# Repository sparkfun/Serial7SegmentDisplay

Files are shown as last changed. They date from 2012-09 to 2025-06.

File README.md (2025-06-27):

7-Segment Serial Display
========================

[7-Segment Serial Display  
*7-Segment Serial Display (COM-11629)*](https://www.sparkfun.com/products/11629)

The 7-Segment Serial Display combines a classic 4-digit 7-segment display and an ATMega328 microcontroller allowing you to control every segment individually using only a few serial lines.

Repository Contents
-------------------

* **/firmware** - Arduino firmware and test code
* **/hardware** - PCB design files (created with Eagle 6.1.0)

Documentation
--------------
* **[Hookup Guide](https://learn.sparkfun.com/tutorials/using-the-serial-7-segment-display)** - Basic hookup guide for the Serial Enabled 7-Segment Displays.
* **[Datasheet](https://github.com/sparkfun/Serial7SegmentDisplay/wiki/Serial-7-Segment-Display-Datasheet)** - Specifications

Product Versions
----------------

**[COM-11629](https://www.sparkfun.com/products/11629) - white, OEM packaging**  
The 7-Segment Serial Display with **white** segments in standard OEM packaging.

**[COM-11442](https://www.sparkfun.com/products/11442) - blue, OEM packaging**  
The 7-Segment Serial Display with **blue** segments in standard OEM packaging.

**[COM-11441](https://www.sparkfun.com/products/11441) - red, OEM packaging**  
The 7-Segment Serial Display with **red** segments in standard OEM packaging.

**[COM-11443](https://www.sparkfun.com/products/11443) - yellow, OEM packaging**  
The 7-Segment Serial Display with **yellow** segments in standard OEM packaging.

**[COM-11440](https://www.sparkfun.com/products/11440) - kelly green, OEM packaging**  
The 7-Segment Serial Display with **kelly green** segments in standard OEM packaging.

**[RTL-11381](https://www.sparkfun.com/products/11381) - blue, retail packaging**  
The 7-Segment Serial Display with **blue** segments in a retail-ready plastic clam shell.

**[RTL-11386](https://www.sparkfun.com/products/11386) - red, retail packaging**  
The 7-Segment Serial Display with **red** segments in a retail-ready plastic clam shell.

License Information
-------------------

All contents of this repository are released under [Creative Commons Share-alike 3.0](http://creativecommons.org/licenses/by-sa/3.0/).

Author
------

Jim Lindblom, [SparkFun Electronics](https://www.sparkfun.com)

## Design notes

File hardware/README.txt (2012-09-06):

////////////////////////////////
/// Serial 7-Segment Display ///
////////////////////////////////
/// PCB Design Files ///////////
////////////////////////////////

These files were created with Eagle 6.1.0.
Serial-7-Segment-Display.sch: Schematic
Serial-7-Segment-Display.brd: PCB Design

This project is Open-source Hardware!

License: Creative Commons Attribution-ShareAlike 3.0 (CC BY-SA 3.0)
http://creativecommons.org/licenses/by-sa/3.0/

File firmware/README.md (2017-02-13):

//////////////////////////////////////<br />
/// Serial 7-Segment Display /////////<br />
//////////////////////////////////////

This folder should live in your Arduino Sketchbook.

Serial 7-Segment Display: This folder contains the Serial 7-Segment Displays firmware and test/example Arduino code.

Support for this board in the Arduino IDE can be found in [this repository](https://github.com/sparkfun/Arduino_Boards/). That adds a "Serial 7-Segment Display" option to the boards menu within Arduino. If you reprogram the Display, you'll need this board selected. Special pin defines were required to make use of new pins 22 and 23 (PB6:7) (in variants/standard/pins_arduino.h). These pins are available on the Serial 7-Segment Display because it runs on the ATmega328's internal 8MHz oscillator.

This project is Open-source!

License: Creative Commons Attribution-ShareAlike 4.0 (CC BY-SA 4.0)
https://creativecommons.org/licenses/by-sa/4.0/

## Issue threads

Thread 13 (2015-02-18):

Adding custom boards does not work for Arduino 1.6.0

pinski1, 2015-02-18:
See https://github.com/arduino/Arduino/wiki/Arduino-Hardware-Cores-migration-guide-from-1.0-to-1.6

teachop, 2015-03-15:
Sparkfun is supporting building for the Serial 7 Segment in Arduino 1.6 here:
https://github.com/sparkfun/Arduino_Boards

Closed 2015-04-02.

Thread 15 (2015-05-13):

Missing 'E' Segment (COM-11440)

morganrallen, 2015-05-13:
This is an issue complained about in several comments across all of the 7 Segment product pages. Where everything appears normal, expect Segment 'E' on each digit does not display. I've verified the hardware is physically connected by switching pin assignments around and it does in fact light up.

Reading comments I've seen and tried several fixes.

Changing BOARD_TYPE to S7S.

Initially the text is totally scrambled, this change fixes it, except the E Segment.

Appending PB6/PB7 to pin_arduino.h

As I'm using the current code from this repo and (I think...) properly installing the hardware profile, this is taken care of for me.

I'm using Arduino 1.6.4

BrentWilkins, 2015-05-14:
I'm a little confused if this is a question/issue.  Are you appending PB6/PB7 to pin_arduino.h?  The copy of pins_arduino.h that is in this repo has had that for 3 years.  Did you change something?  Does 'Changing BOARD_TYPE to S7S' mean you changed line #39 of Serial_7_Segment_Display_Firmware.ino (#define DISPLAY_TYPE OPENSEGMENT) to use the S7S settings?

morganrallen, 2015-05-14:
Sorry for the lack of clarity.
I've not added anything to pins_arduino.h, as you've said it's present, but that is part of what I found to be a suggested solution.

And yes, I've changed #define BOARD_TYPE to S7S. Which leads to better results than default but still seems to miss segment E.

jimblom, 2015-05-14:
I think I've tracked the problem down. The build variant was set incorrectly to "standard", so _pins\_arduino.h_ wasn't being pulled from our custom hardware folder.

I pushed a new version of boards.txt, if you want to try that out. Or just make sure [this line](https://github.com/sparkfun/Serial7SegmentDisplay/blob/master/firmware/hardware/Serial7Seg/boards.txt#L17) says "ser7seg" not "standard".

morganrallen, 2015-05-14:
But wouldn't that require the directory `variant/ser7seg` to exist with it's own pin_arduino.h?

```
In file included from /home/morgan/opt/arduino-1.6.4/libraries/SevSeg/src/SevSeg.h:14:0,
                 from Serial_7_Segment_Display_Firmware.ino:1:
/home/morgan/opt/arduino-1.6.4/hardware/Serial7Seg/avr/cores/arduino/Arduino.h:213:26: fatal error: pins_arduino.h: No such file or directory
 #include "pins_arduino.h"
```

BrentWilkins, 2015-05-14:
It does. https://github.com/sparkfun/Serial7SegmentDisplay/blob/master/firmware/hardware/Serial7Seg/variants/standard/pins_arduino.h
Maybe do a fresh download?

morganrallen, 2015-05-14:
Same error with a fresh checkout. If I set `variant` to `ser7seg` it cannot find `pins_arduino.h`.

jimblom, 2015-05-14:
@morganrallen is right. "standard" should be renamed "ser7seg". Those changes are pushed now.

Bigger picture issue here is the hardware folder structure in general needs to be revised to match Arduino 1.6 standards. I'll keep this issue open until we resolve that.

morganrallen, 2015-05-14:
Right, I've had to add the `avr` directory to even get it to load, platforms.txt is missing also.

morganrallen, 2015-05-14:
So simply renaming everything hasn't worked. I got it back to a compiling state but Segment E remains dark.

jimblom, 2015-05-14:
Another change pushed. Moved all hardware addon files to `hardware/sparkfun/avr`, and added platform.txt. Seems to be working for me - compiles and the E segment lights up. Let me know if it tests out for you @morganrallen .

morganrallen, 2015-05-14:
No dice.

BrentWilkins, 2017-02-13:
I cannot reproduce the error. What do you mean by the 'E' segment? Is it a single segment that is numbered in a figure in [this section](https://github.com/sparkfun/Serial7SegmentDisplay/wiki/Special-Commands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)? If so, which digit(s)?

morganrallen, 2017-02-16:
Yes, E is the same as 5.

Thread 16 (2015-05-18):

Display something on power up

josephernest, 2015-05-18:
I'm using the 7segment display with a raspberry pi.
During the Linux booting time (~15 seconds), the 7segment display **displays nothing**.

Is it possible to show  "___", "----"  once it is powered up?

So the user will know the system is "booting".

How to do this?

jimblom, 2015-05-18:
Sure, this is a relatively simple modification. The four variable assignments starting [here](https://github.com/sparkfun/Serial7SegmentDisplay/blob/master/firmware/Serial%207-Segment%20Display/Serial_7_Segment_Display_Firmware/Serial_7_Segment_Display_Firmwa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) set what the display shows on start-up.

For example, to make the display show "----", swap in these four lines of code:

    display.digits[0] = '-';
    display.digits[1] = '-';
    display.digits[2] = '-';
    display.digits[3] = '-';

josephernest, 2015-05-18:
So do you mean it should *already* display something on power up?  (it seems, in your code, that `1234` should be displayed on power up, or am I wrong?).

I just tried by connecting +5V and GND only  (and no serial, no I2C), but nothing is displayed.

When exactly should these default letters happen? Really when +5V comes ? or is there another trigger for the "startup"?

Closed 2015-05-18.

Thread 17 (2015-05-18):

Refresh rate / flicker

josephernest, 2015-05-18:
I'm currently filming my hardware project (including a 7seg display) with a camera.

The result is *flickering* because probably the refresh rate does not fit well with 24fps or 30fps of my camera.

Any idea on how to change refresh rate of Serial7SegmentDisplay?

jimblom, 2015-05-18:
You'll have to modify the [SevSeg library](https://github.com/sparkfun/SevSeg) to achieve this. The constant `FRAMEPERIOD`, defined [here](https://github.com/sparkfun/SevSeg/blob/master/src/SevSeg.h#L28) is probably the best place to begin experimenting. Try turning it to somewhere between 500-1000.

josephernest, 2015-05-18:
In fact the problem has been solved by changing the shutter speed of the
camera (didn't know it was possible in "Movie" mode).
Setting shutter speed to 1/30 or 1/50 worked.

On Mon, May 18, 2015 at 5:09 PM, Jim Lindblom <notifications@github.com>
wrote:

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

Closed 2015-05-18.

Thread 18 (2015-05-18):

Error check

josephernest, 2015-05-18:
I use Serial7SegmentDisplay with a RaspberryPi. It works both with I2C, and with Serial.

Everything is fine 90% of the time. But sometimes, some characters are not well sent/received by the display, and one character is missing. This is happening for some other people (I found on some forums).

Could we add basic error check, so that if a byte is not well received, the serial or SPI interface will resend?

Tried:

* sleep 5 ms between each byte send, it improves a bit but does not solve 100%
* change bps rate, but doesn't change anything

glebtv, 2015-06-06:
https://github.com/sparkfun/Serial7SegmentDisplay/blob/master/firmware/Serial%207-Segment%20Display/Serial_7_Segment_Display_Firmware/Serial_7_Segment_Display_Firmwa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

I think it's a bug somewhere here, whenever you set a 0x76 to the display it clears and moves cursor
Example (setting brightness to 117)
```
s7sSendStringI2C("TEST");
delay(500);
Wire.beginTransmission(s7sAddress);
Wire.write(0x7A);  // Set brightness command byte
Wire.write(0x76);  // brightness data byte
Wire.endTransmission();
delay(500);
```

josephernest, 2015-06-07:
@glebtv What do you mean?

Do you think it's impossible to send a 0x76 value for brightness for example? It will always clear the display?

I cannot test now, but are you sure?
@jimblom what do you think?

glebtv, 2015-07-19:
Yes, the firmware code checks for reset before checking for anything else so sending 0x76 (reset) as brightness or any other DATA it resets the display - which gives exactly the effect described in this issue - a couple characters will be missing from display.
I found that accidentally by testing different brightness levels in a loop.

See code I linked https://github.com/sparkfun/Serial7SegmentDisplay/blob/master/firmware/Serial%207-Segment%20Display/Serial_7_Segment_Display_Firmware/Serial_7_Segment_Display_Firmwa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

jimblom, 2016-01-21:
Sorry to be so late on this. I've added a check for a current commandMode before clearing the display. That seems to fix the bug.

Closed 2016-01-21.

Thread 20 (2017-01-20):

Display refresh rate

MNewman, 2017-01-20:
I've noticed that when viewed on a 60fps camera the display visibly flickers. I assume this has something to do with the rate at which the segments are illuminated. I'm also assuming that one potential remedy would be adjusting the shutter rate of the camera.

Is dimming accomplished by leaving each segment on a smaller slice of time? Is there a way to increase the speed of redrawing the segments to overcome the aliasing effect on the camera?

bboyho, 2020-06-02:
Hi,

Sorry, I just noticed this question when browsing our issues. If you are still wondering, the brightness uses an internal PWM with a work around. The work around turns on and off the segments at a certain speed. This speed is probably not synced with your camera which is what you are seeing with the flicker. If you were adjusting the code, you may need to adjust the [`SetBrightness()` function in the library](https://github.com/sparkfun/SevSeg/blob/master/src/SevSeg.cpp#L175) and reupload the [default firmware](https://github.com/sparkfun/Serial7SegmentDisplay/tree/master/firmware/Serial%207-Segment%20Display/Serial_7_Segment_Display_Firmware). Looking online, it looks like users implemented the `millis()` function in their sketch and only updated the segments after a certain amount of time had passed.

I don't know too much about DSLR cameras. Doing some research online, it seems like the flicker can be avoided by adjusting the shutter speed to match the time of the segments turning on and off. Another technique would be to adjust the frame rate equal to the period of the segments blinking as well. These two techniques seem to be used to compensate for flickers in general.

You may want to post in the following forums to see if anyone else in the community has additional insight. It appears that this question about the flickering has been asked a few times in the Arduino forums. Otherwise, you would need to experiment with the code or your camera's settings if you are still having this problem.

* {SparkFun Forums](https://forum.sparkfun.com/)
* [Arduino Forums](https://forum.arduino.cc/)

Closed 2020-06-02.

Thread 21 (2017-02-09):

basic display driver

Dc2LightTech, 2017-02-09:
I need to display temperatures from -99.9 to 99.9 (with the leading digit blanked when the value is positive.
I will be driving 10 serial displays and I need to assign the CS pin.

BrentWilkins, 2017-02-09:
Thanks for reaching out. The specific issue you are commenting on here is unclear. If you have found a specific bug in our code, please let us know. Otherwise, if you are simply looking to modify the code for your personal project, we have an example sketch for changing the SPI settings [here](https://github.com/sparkfun/Serial7SegmentDisplay/blob/master/firmware/Serial%207-Segment%20Display/Arduino_Examples/S7S_Example_SPI_Settings/S7S_Example_SPI_Setting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).

Dc2LightTech, 2017-02-09:
thanks for the reply. when I used ProMini's the example code worked well.
this was like 5 years ago. Now I only use Teency's and the example code
mostly does not work. the new GitHub SPI Bus code for the displays from:
https://github.com/sparkfun/Serial7SegmentDisplay don't have chip and stuff
for example, the folloning code is not helpull in getting basic display
operation    S7S_EcampleSerial_Basic:  ( I would like to display{-12.3}

/*
 9-23-2012
 Spark Fun Electronics
 Nathan Seidle

 This code is public domain but you buy me a beer if you use this and we
meet someday (Beerware license).
 Serial7Segment is an open source seven segment display.
 This is example code that shows how to display basic numbers on the
display.

 Note: This code expects the display to be listening at 9600bps. If your
display is not at 9600bps, you can
 do a software or hardware reset. See the Wiki for more info:

http://github.com/sparkfun/Serial7SegmentDisplay/wiki/Special-Commands#wiki-baud

 To get this code to work, attached an Serial7Segment to an Arduino Uno
using the following pins:
 Pin 8 on Uno (software serial TX) to RX on Serial7Segment
 VIN to PWR
 GND to GND

*/
#include <SoftwareSerial.h>
SoftwareSerial Serial7Segment(7, 8); //RX pin, TX pin
int cycles = 0;
void setup() {
  Serial.begin(9600);
  Serial.println("OpenSegment Example Code");
  Serial7Segment.begin(9600); //Talk to the Serial7Segment at 9600 bps
  Serial7Segment.write('v'); //Reset the display - this forces the cursor
to return to the beginning of the display
}
void loop()
{
  cycles++; //Counting cycles! Yay!
  Serial.print("Cycle: ");
  Serial.println(cycles);

  char tempString[10]; //Used for sprintf
  sprintf(tempString, "%4d", cycles); //Convert deciSecond into a string
that is right adjusted
  //sprintf(tempString, "%d", cycles); //Convert deciSecond into a string
that is left adjusted (requires digit 1 command)
  //sprintf(tempString, "%04d", cycles); //Convert deciSecond into a string
with leading zeros
  //sprintf(tempString, "%4X", cycles); //Count in HEX, right adjusted
  //int negativeCycles = cycles * -1;
  //sprintf(tempString, "%4d", negativeCycles); //Shows a negative sign
infront of right adjusted number
  //Note: This method works well as long as your number is less than or
equal to 4 digits.
  //14422 will cause the display to wrap (5 digits)
  //-5766 will cause the display to wrap (5 digits)
  //To fix this, send a 'v' character or look at how to control the digit
placement
  //
https://github.com/sparkfun/Serial7SegmentDisplay/wiki/Basic-Usage#wiki-cursor
  Serial7Segment.print(tempString); //Send serial string out the soft
serial port to the S7S
  delay(10);
}

On Thu, Feb 9, 2017 at 2:13 PM, Brent Wilkins <notifications@github.com>
wrote:

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

BrentWilkins, 2017-02-14:
I wasn't able to reproduce any issues with the code found in S7S_Example_Serial_Basic on a Teensy. I wired up the TX line on the Teensy (8) to the RX line in the display module. To display your example of "-12.3" I replaced the contents of `loop()` with the following code:

```c++
// Writing 4 digits each time. In this case no need to clear display.
Serial7Segment.print("-123");
Serial7Segment.write(0x77); // Decimal control command
Serial7Segment.write(0b00000100); // Turns on tenths decimal
```

In other cases you might want to send the reset command (RESET_CMD | 0x76 | 'v') first. This might be `Serial7Segment.print("v-123");` for this case.

If you want to modify the firmware to handle numbers rather than ASCII characters and commands, take a look at the `void SevSeg::DisplayString(const char*, byte)` method found [here](https://github.com/sparkfun/SevSeg/blob/master/src/SevSeg.cpp). I replaced line 114 in [the firmware](https://github.com/sparkfun/Serial7SegmentDisplay/blob/master/firmware/Serial%207-Segment%20Display/Serial_7_Segment_Display_Firmware/Serial_7_Segment_Display_Firmwa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) `myDisplay.DisplayString(display.digits, display.decimals);` with `myDisplay.DisplayString("-123", 4);` to display `-12.3`.

Do you have our SevSeg library installed? If you have the original library that we forked, not ours, you will get errors such as `error: 'class SevSeg' has no member named 'DisplayString'`.

Dc2LightTech, 2017-02-15:
could you send the entire code please. This code is SPI not I2C, right?

On Tue, Feb 14, 2017 at 4:20 PM, Brent Wilkins <notifications@github.com>
wrote:

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

BrentWilkins, 2017-02-15:
Here is the entire sketch minus the copyright and such in the header.

```C++
#include <SoftwareSerial.h>

SoftwareSerial Serial7Segment(7, 8); //RX pin, TX pin

int cycles = 0;

void setup() {

  Serial.begin(9600);
  delay(4000);
  Serial.println("OpenSegment Example Code");

  Serial7Segment.begin(9600); //Talk to the Serial7Segment at 9600 bps
  Serial7Segment.write('v'); //Reset the display - this forces the cursor to return to the beginning of the display
}

void loop()
{
  Serial.println("Displaying: -12.3");
  // Writing 4 digits each time. In this case no need to clear display.
  Serial7Segment.print("-123");
  Serial7Segment.write(0x77); // Decimal control command
  Serial7Segment.write(0b00000100); // Turns on tenths decimal
}
```
The first line includes the file with the [software UART implementation](https://www.arduino.cc/en/Reference/softwareSerial). The next line of code creates an instance of the SoftwareSerial class named `Serial7Segment` that uses pins 7 & 8.
If you want to use SPI instead, I recommend looking at our [SPI example](https://github.com/sparkfun/Serial7SegmentDisplay/blob/master/firmware/Serial%207-Segment%20Display/Arduino_Examples/S7S_Example_SPI_Basic/S7S_Example_SPI_Basic.ino).

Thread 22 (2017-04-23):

Analog inputs

OmriShi, 2017-04-23:
Hi,
My name is Omri, and I'm considering the use of your nice S7S for a project I'm working on.

The main goal is using this S7S to display voltage measurements. By considering the 2 analog input pins there is on the breakout board it could be more simple than I thought.

After reading the "Hardware specifications" I'm a little bit confused.
With the current stat of the breakout and firmware,  can I use the pins to measure the analog voltage?
and if I can, what is the voltage limitation?

I hope I was clear, thanks for helping

bboyho, 2019-05-16:
Hi,

I'm sorry for the delay in reply. I was browsing the issues in our GitHub repo when I noticed your question. This is a more technical question and it does not seem to be an issue with the board. It might have been better to have checked in the SparkFun Forums. However, here are some of my thoughts regarding your question if you are still working on the project:

The voltage limitation on the pins depends on the input voltage (Vcc). As stated in the Hardware Overview in the [Wiki](https://github.com/sparkfun/Serial7SegmentDisplay/wiki/Hardware-specifications) and [associated tutorial](https://learn.sparkfun.com/tutorials/using-the-serial-7-segment-display#hardware-overview), it is **3.0V to 5.5V**. Based on the input voltage of the ATmega328P as stated in the [datasheet under the **Absolute Maximum Rating**](http://ww1.microchip.com/downloads/en/DeviceDoc/Atmel-7810-Automotive-Microcontrollers-ATmega328P_Datasheet.pdf), that should be about Vcc+/-0.5V on any I/O pin. So if you are powering the device with 3.3V, the limitation on the pins is about 3.3V.

However, using a [voltage divider](https://learn.sparkfun.com/tutorials/voltage-dividers/all#applications), you can theoretically measure higher voltage than your input voltage. I have not tried the method using resistors before but here's one example that I found online => [ [https://startingelectronics.org/articles/arduino/measuring-voltage-with-arduino](https://startingelectronics.org/articles/arduino/measuring-voltage-with-arduino/) ]. You would just need to adjust the default firmware that is loaded on the board to measure and display the values on the 7 segments display.

Otherwise, try looking at this dedicated [digital 7-segment LED Voltmeter](https://www.sparkfun.com/products/14313).

Closed 2019-05-16.

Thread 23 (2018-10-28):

Technical data for Sparkfun PCB missing -- measures provided

sorenoneill, 2018-10-28:
I have searched but not been able to find the technical data for the PCB dimensions. Data is available for the 7-segment display itself, but not the PCB.

These are my measures using a caliper:

width: 41.3mm
depth: 23.5mm
thickness: 1.6mm

stand-off holes diameter: 3.0mm
stand-off holes width offset (to center of hole): 5.2 (possibly should be 0.2in)
stand-off holes depth offset (to center of hole): 2.7 (possibly should be 0.1in)

bboyho, 2019-02-12:
Hi,

Thanks for the measurements. The dimensions (except for the PCB thickness) are actually provided in inches under the [hardware specifications under this repository's Wiki](https://github.com/sparkfun/Serial7SegmentDisplay/wiki/Hardware-specifications#physical-dimensions):

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

I'll be closing this issue out. =)

Closed 2019-02-12.

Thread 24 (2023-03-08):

Compilation Error

Tommy38cal, 2023-03-08:
Hi,
I am getting two compilation errors in the Arduino IDE. One was a capitalization error on setBrightness. The other is

Compilation error: 'class SevSeg' has no member named 'displayString'

I couldn't find this function in the SevSeg .cpp or .h. Can you advise? I thought it might have just been a mistake and looked for other ones that have the same inputs but to no avail. I think setChars was the closest.

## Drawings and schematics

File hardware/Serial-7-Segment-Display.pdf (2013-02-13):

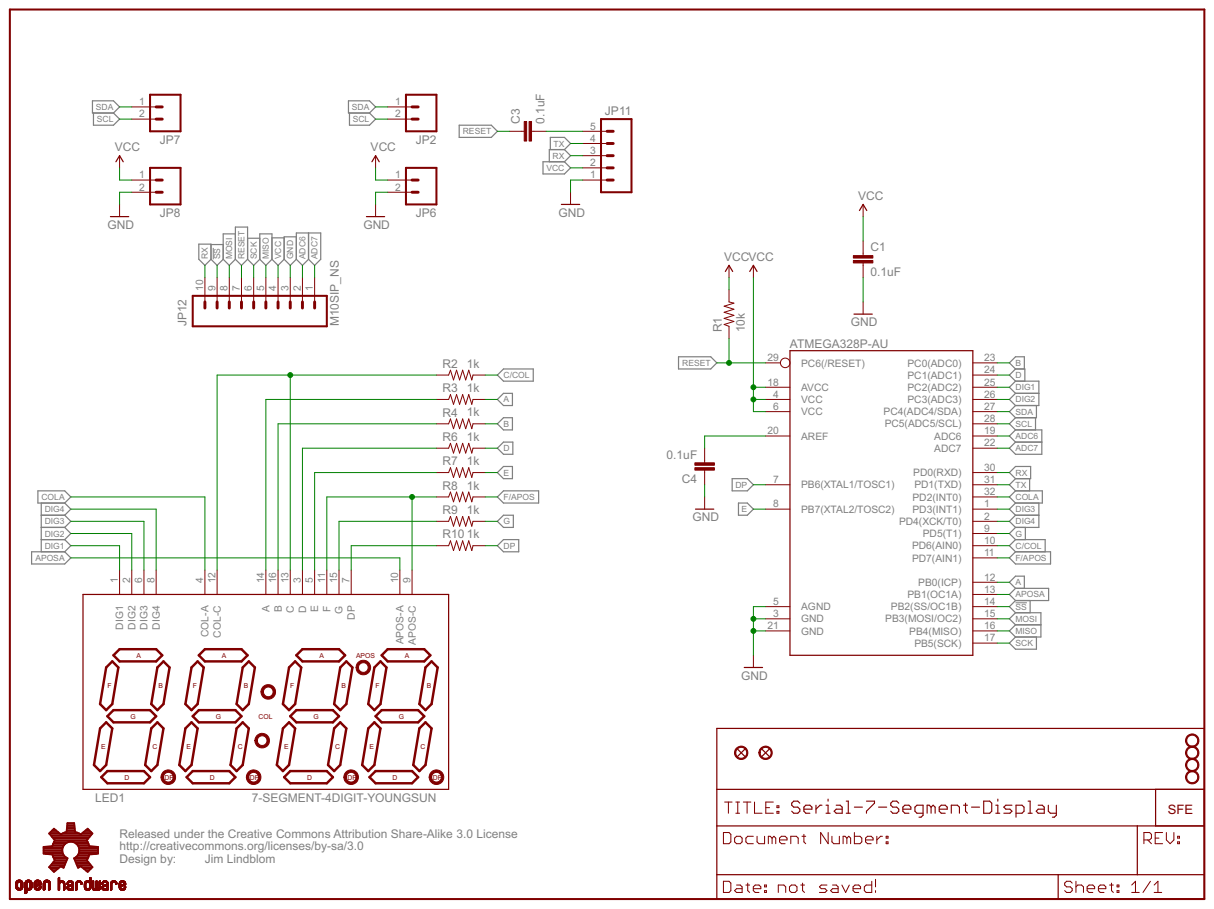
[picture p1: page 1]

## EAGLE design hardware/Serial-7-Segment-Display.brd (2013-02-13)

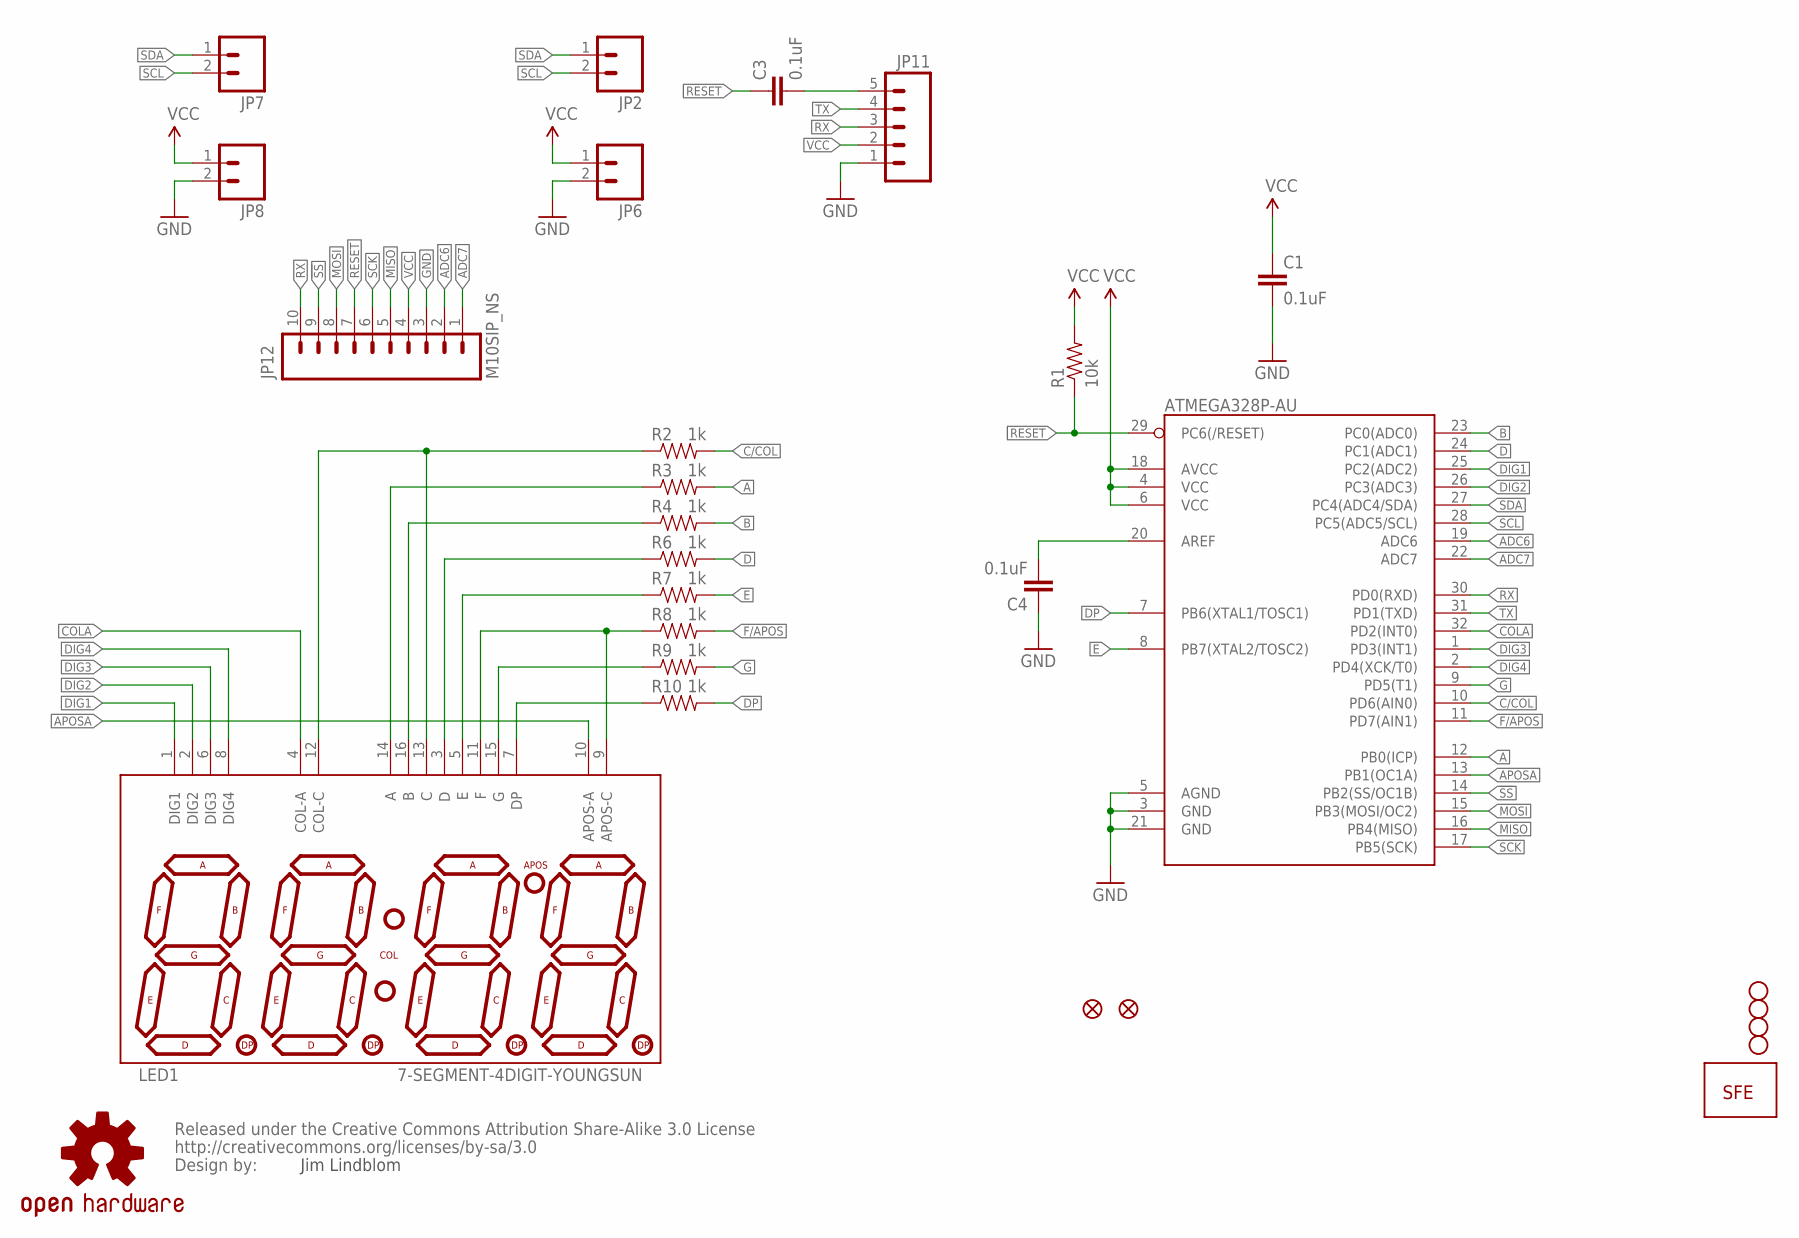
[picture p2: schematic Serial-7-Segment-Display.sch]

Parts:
ATMEGA328P-AU: ATMEGA328P-AU; TQFP32-08
C1, C3, C4: 0.1uF; 0402-CAP
JP1, JP3, JP4, JP5: STAND-OFF
JP2, JP6, JP7, JP8: M021X02_NO_SILK; 1X02_NO_SILK
JP9, JP10: FIDUCIALUFIDUCIAL; MICRO-FIDUCIAL
JP11: M05PTH-NS; 1X05_NO_SILK
JP12: M10SIP_NS; 1X10_NO_SILK
LED1: 7-SEGMENT-4DIGIT-YOUNGSUN
R1: 10k; 0402-RES
R2, R3, R4, R6, R7, R8, R9, R10: 1k; 0402-RES
U$1: CREATIVE_COMMONS
U$2: LOGO-SFESK; SFE-LOGO-FLAME
U$4: OSHW-LOGOS; OSHW-LOGO-S

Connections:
!SS: ATMEGA328P-AU.14 (PB2(SS/OC1B)), JP12.9
A: ATMEGA328P-AU.12 (PB0(ICP)), R3.2
ADC6: ATMEGA328P-AU.19 (ADC6), JP12.2
ADC7: ATMEGA328P-AU.22 (ADC7), JP12.1
APOSA: ATMEGA328P-AU.13 (PB1(OC1A)), LED1.10 (APOS-A)
B: ATMEGA328P-AU.23 (PC0(ADC0)), R4.2
C/COL: ATMEGA328P-AU.10 (PD6(AIN0)), R2.2
COLA: ATMEGA328P-AU.32 (PD2(INT0)), LED1.4 (COL-A)
D: ATMEGA328P-AU.24 (PC1(ADC1)), R6.2
DIG1: ATMEGA328P-AU.25 (PC2(ADC2)), LED1.1 (DIG1)
DIG2: ATMEGA328P-AU.26 (PC3(ADC3)), LED1.2 (DIG2)
DIG3: ATMEGA328P-AU.1 (PD3(INT1)), LED1.6 (DIG3)
DIG4: ATMEGA328P-AU.2 (PD4(XCK/T0)), LED1.8 (DIG4)
DP: ATMEGA328P-AU.7 (PB6(XTAL1/TOSC1)), R10.2
E: ATMEGA328P-AU.8 (PB7(XTAL2/TOSC2)), R7.2
F/APOS: ATMEGA328P-AU.11 (PD7(AIN1)), R8.2
G: ATMEGA328P-AU.9 (PD5(T1)), R9.2
GND: ATMEGA328P-AU.3 (GND), ATMEGA328P-AU.5 (AGND), ATMEGA328P-AU.21 (GND), C1.2, C4.1, JP6.2, JP8.2, JP11.1, JP12.3
MISO: ATMEGA328P-AU.16 (PB4(MISO)), JP12.5
MOSI: ATMEGA328P-AU.15 (PB3(MOSI/OC2)), JP12.8
unnamed: ATMEGA328P-AU.20 (AREF), C4.2
unnamed: LED1.7 (DP), R10.1
unnamed: LED1.15 (G), R9.1
unnamed: LED1.9 (APOS-C), LED1.11 (F), R8.1
unnamed: LED1.5 (E), R7.1
unnamed: LED1.3 (D), R6.1
unnamed: LED1.16 (B), R4.1
unnamed: LED1.14 (A), R3.1
unnamed: LED1.12 (COL-C), LED1.13 (C), R2.1
unnamed: C3.2, JP11.5
RESET: ATMEGA328P-AU.29 (PC6(/RESET)), C3.1, JP12.7, R1.1
RX: ATMEGA328P-AU.30 (PD0(RXD)), JP11.3, JP12.10
SCK: ATMEGA328P-AU.17 (PB5(SCK)), JP12.6
SCL: ATMEGA328P-AU.28 (PC5(ADC5/SCL)), JP2.2, JP7.2
SDA: ATMEGA328P-AU.27 (PC4(ADC4/SDA)), JP2.1, JP7.1
TX: ATMEGA328P-AU.31 (PD1(TXD)), JP11.4
VCC: ATMEGA328P-AU.4 (VCC), ATMEGA328P-AU.6 (VCC), ATMEGA328P-AU.18 (AVCC), C1.1, JP6.1, JP8.1, JP11.2, JP12.4, R1.2

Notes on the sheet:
Jim Lindblom

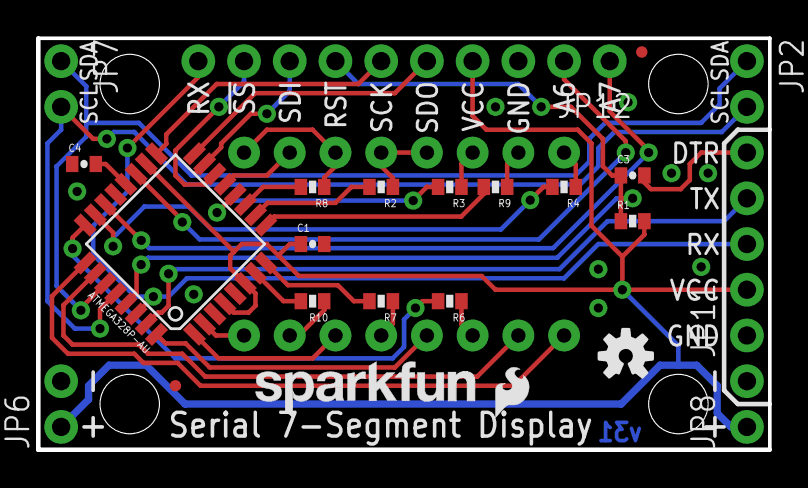
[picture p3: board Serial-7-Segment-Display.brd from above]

Board: 2 copper layers, 40.6 x 22.9 mm, 30 parts (1 on the bottom side), 37 nets.

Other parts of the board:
U$3: LOGO-SFENW2; SFE-NEW-WEB

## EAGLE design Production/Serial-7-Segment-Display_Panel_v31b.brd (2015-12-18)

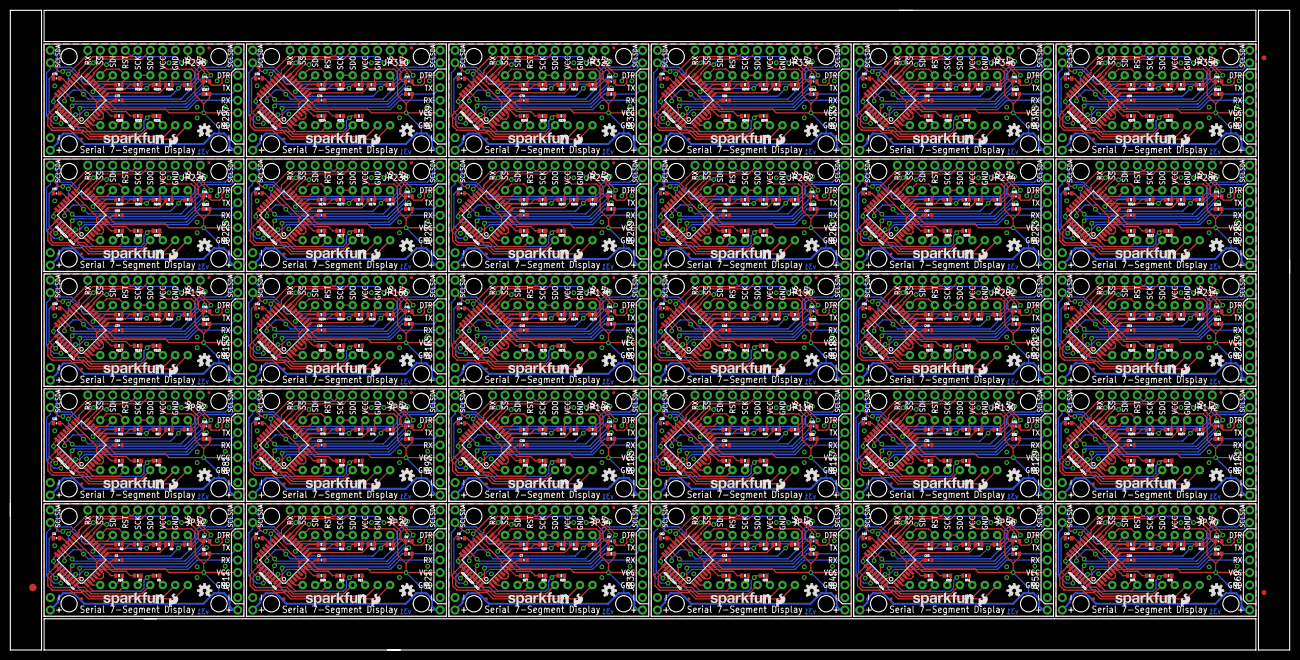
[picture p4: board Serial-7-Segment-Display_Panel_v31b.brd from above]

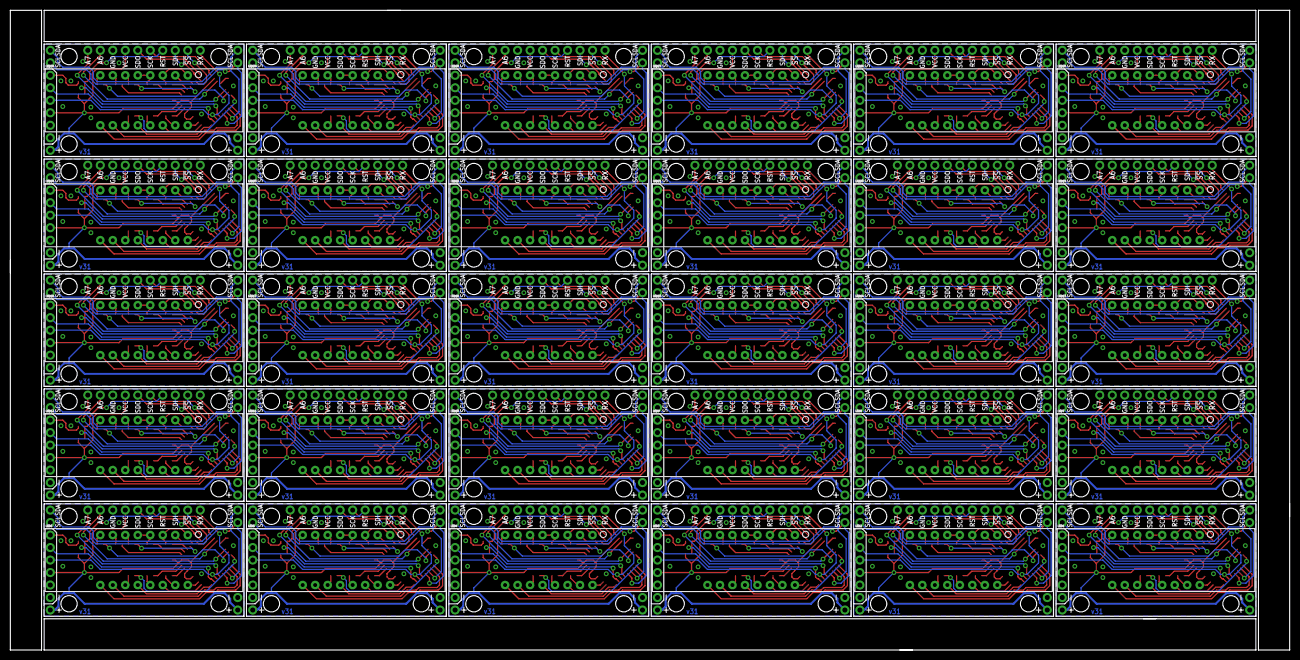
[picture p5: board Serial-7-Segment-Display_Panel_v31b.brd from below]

Board: 2 copper layers, 260.1 x 130.0 mm, 873 parts (30 on the bottom side), 1110 nets.

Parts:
ATMEGA328P-AU, ATMEGA328P-AU1, ATMEGA328P-AU2, ATMEGA328P-AU3, ATMEGA328P-AU4, ATMEGA328P-AU5, ATMEGA328P-AU6, ATMEGA328P-AU7, ATMEGA328P-AU8, ATMEGA328P-AU9, ATMEGA328P-AU10, ATMEGA328P-AU11, ATMEGA328P-AU12, ATMEGA328P-AU13, ATMEGA328P-AU14, ATMEGA328P-AU15, ATMEGA328P-AU16, ATMEGA328P-AU17, ATMEGA328P-AU18, ATMEGA328P-AU19, ATMEGA328P-AU20, ATMEGA328P-AU21, ATMEGA328P-AU22, ATMEGA328P-AU23, ATMEGA328P-AU24, ATMEGA328P-AU25, ATMEGA328P-AU26, ATMEGA328P-AU27, ATMEGA328P-AU28, ATMEGA328P-AU29: ATMEGA328P-AU; TQFP32-08
C1, C2, C3, C4, C5, C6, C7, C8, C9, C10, C11, C12, C13, C14, C15, C16, C17, C18, C19, C20, C21, C22, C23, C24, C25, C26, C27, C28, C29, C30, C31, C32, C33, C34, C35, C36, C37, C38, C39, C40, C41, C42, C43, C44, C45, C46, C47, C48, C49, C50, C51, C52, C53, C54, C55, C56, C57, C58, C59, C60, C61, C62, C63, C64, C65, C66, C67, C68, C69, C70, C71, C72, C73, C74, C75, C76, C77, C78, C79, C80, C81, C82, C83, C84, C85, C86, C87, C88, C89, C90: 0.1uF; 0402-CAP
E$1: FIDUCIAL-1.5X3
E$5, E$6: FIDUCIAL-1X2
JP1, JP3, JP4, JP5, JP13, JP14, JP15, JP16, JP25, JP26, JP27, JP28, JP37, JP38, JP39, JP40, JP49, JP50, JP51, JP52, JP61, JP62, JP63, JP64, JP73, JP74, JP75, JP76, JP85, JP86, JP87, JP88, JP97, JP98, JP99, JP100, JP109, JP110, JP111, JP112, JP121, JP122, JP123, JP124, JP133, JP134, JP135, JP136, JP145, JP146, JP147, JP148, JP157, JP158, JP159, JP160, JP169, JP170, JP171, JP172, JP181, JP182, JP183, JP184, JP193, JP194, JP195, JP196, JP205, JP206, JP207, JP208, JP217, JP218, JP219, JP220, JP229, JP230, JP231, JP232, JP241, JP242, JP243, JP244, JP253, JP254, JP255, JP256, JP265, JP266, JP267, JP268, JP277, JP278, JP279, JP280, JP289, JP290, JP291, JP292, JP301, JP302, JP303, JP304, JP313, JP314, JP315, JP316, JP325, JP326, JP327, JP328, JP337, JP338, JP339, JP340, JP349, JP350, JP351, JP352: STAND-OFF
JP2, JP6, JP7, JP8, JP17, JP18, JP19, JP20, JP29, JP30, JP31, JP32, JP41, JP42, JP43, JP44, JP53, JP54, JP55, JP56, JP65, JP66, JP67, JP68, JP77, JP78, JP79, JP80, JP89, JP90, JP91, JP92, JP101, JP102, JP103, JP104, JP113, JP114, JP115, JP116, JP125, JP126, JP127, JP128, JP137, JP138, JP139, JP140, JP149, JP150, JP151, JP152, JP161, JP162, JP163, JP164, JP173, JP174, JP175, JP176, JP185, JP186, JP187, JP188, JP197, JP198, JP199, JP200, JP209, JP210, JP211, JP212, JP221, JP222, JP223, JP224, JP233, JP234, JP235, JP236, JP245, JP246, JP247, JP248, JP257, JP258, JP259, JP260, JP269, JP270, JP271, JP272, JP281, JP282, JP283, JP284, JP293, JP294, JP295, JP296, JP305, JP306, JP307, JP308, JP317, JP318, JP319, JP320, JP329, JP330, JP331, JP332, JP341, JP342, JP343, JP344, JP353, JP354, JP355, JP356: 1X02_NO_SILK
JP9, JP10, JP23, JP24, JP35, JP36, JP47, JP48, JP59, JP60, JP71, JP72, JP83, JP84, JP95, JP96, JP107, JP108, JP119, JP120, JP131, JP132, JP143, JP144, JP155, JP156, JP167, JP168, JP179, JP180, JP191, JP192, JP203, JP204, JP215, JP216, JP227, JP228, JP239, JP240, JP251, JP252, JP263, JP264, JP275, JP276, JP287, JP288, JP299, JP300, JP311, JP312, JP323, JP324, JP335, JP336, JP347, JP348, JP359, JP360: FIDUCIALUFIDUCIAL; MICRO-FIDUCIAL
JP11, JP21, JP33, JP45, JP57, JP69, JP81, JP93, JP105, JP117, JP129, JP141, JP153, JP165, JP177, JP189, JP201, JP213, JP225, JP237, JP249, JP261, JP273, JP285, JP297, JP309, JP321, JP333, JP345, JP357: 1X05_NO_SILK
JP12, JP22, JP34, JP46, JP58, JP70, JP82, JP94, JP106, JP118, JP130, JP142, JP154, JP166, JP178, JP190, JP202, JP214, JP226, JP238, JP250, JP262, JP274, JP286, JP298, JP310, JP322, JP334, JP346, JP358: M10SIP_NS; 1X10_NO_SILK
LED1, LED2, LED3, LED4, LED5, LED6, LED7, LED8, LED9, LED10, LED11, LED12, LED13, LED14, LED15, LED16, LED17, LED18, LED19, LED20, LED21, LED22, LED23, LED24, LED25, LED26, LED27, LED28, LED29, LED30: 7-SEGMENT-4DIGIT-YOUNGSUN
R1, R5, R19, R28, R37, R46, R55, R64, R73, R82, R91, R100, R109, R118, R127, R136, R145, R154, R163, R172, R181, R190, R199, R208, R217, R226, R235, R244, R253, R262: 10k; 0402-RES
R2, R3, R4, R6, R7, R8, R9, R10, R11, R12, R13, R14, R15, R16, R17, R18, R20, R21, R22, R23, R24, R25, R26, R27, R29, R30, R31, R32, R33, R34, R35, R36, R38, R39, R40, R41, R42, R43, R44, R45, R47, R48, R49, R50, R51, R52, R53, R54, R56, R57, R58, R59, R60, R61, R62, R63, R65, R66, R67, R68, R69, R70, R71, R72, R74, R75, R76, R77, R78, R79, R80, R81, R83, R84, R85, R86, R87, R88, R89, R90, R92, R93, R94, R95, R96, R97, R98, R99, R101, R102, R103, R104, R105, R106, R107, R108, R110, R111, R112, R113, R114, R115, R116, R117, R119, R120, R121, R122, R123, R124, R125, R126, R128, R129, R130, R131, R132, R133, R134, R135, R137, R138, R139, R140, R141, R142, R143, R144, R146, R147, R148, R149, R150, R151, R152, R153, R155, R156, R157, R158, R159, R160, R161, R162, R164, R165, R166, R167, R168, R169, R170, R171, R173, R174, R175, R176, R177, R178, R179, R180, R182, R183, R184, R185, R186, R187, R188, R189, R191, R192, R193, R194, R195, R196, R197, R198, R200, R201, R202, R203, R204, R205, R206, R207, R209, R210, R211, R212, R213, R214, R215, R216, R218, R219, R220, R221, R222, R223, R224, R225, R227, R228, R229, R230, R231, R232, R233, R234, R236, R237, R238, R239, R240, R241, R242, R243, R245, R246, R247, R248, R249, R250, R251, R252, R254, R255, R256, R257, R258, R259, R260, R261, R263, R264, R265, R266, R267, R268, R269, R270: 1k; 0402-RES
U$1, U$3, U$7, U$10, U$13, U$16, U$19, U$22, U$25, U$28, U$31, U$34, U$37, U$40, U$43, U$46, U$49, U$52, U$55, U$58, U$61, U$64, U$67, U$70, U$73, U$76, U$79, U$82, U$85, U$88: LOGO-SFENW2; SFE-NEW-WEB
U$2, U$5, U$8, U$11, U$14, U$17, U$20, U$23, U$26, U$29, U$32, U$35, U$38, U$41, U$44, U$47, U$50, U$53, U$56, U$59, U$62, U$65, U$68, U$71, U$74, U$77, U$80, U$83, U$86, U$89: LOGO-SFESK; SFE-LOGO-FLAME
U$4, U$6, U$9, U$12, U$15, U$18, U$21, U$24, U$27, U$30, U$33, U$36, U$39, U$42, U$45, U$48, U$51, U$54, U$57, U$60, U$63, U$66, U$69, U$72, U$75, U$78, U$81, U$84, U$87, U$90: OSHW-LOGOS; OSHW-LOGO-S

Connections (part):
!SS: ATMEGA328P-AU.14, JP12.9
!SS1: ATMEGA328P-AU1.14, JP22.9
!SS2: ATMEGA328P-AU2.14, JP34.9
!SS3: ATMEGA328P-AU3.14, JP46.9
!SS4: ATMEGA328P-AU4.14, JP58.9
!SS5: ATMEGA328P-AU5.14, JP70.9
!SS6: ATMEGA328P-AU6.14, JP82.9
!SS7: ATMEGA328P-AU7.14, JP94.9
!SS8: ATMEGA328P-AU8.14, JP106.9
!SS9: ATMEGA328P-AU9.14, JP118.9
!SS10: ATMEGA328P-AU10.14, JP130.9
!SS11: ATMEGA328P-AU11.14, JP142.9
!SS12: ATMEGA328P-AU12.14, JP154.9
!SS13: ATMEGA328P-AU13.14, JP166.9
!SS14: ATMEGA328P-AU14.14, JP178.9
!SS15: ATMEGA328P-AU15.14, JP190.9
!SS16: ATMEGA328P-AU16.14, JP202.9
!SS17: ATMEGA328P-AU17.14, JP214.9
!SS18: ATMEGA328P-AU18.14, JP226.9
!SS19: ATMEGA328P-AU19.14, JP238.9
!SS20: ATMEGA328P-AU20.14, JP250.9
!SS21: ATMEGA328P-AU21.14, JP262.9
!SS22: ATMEGA328P-AU22.14, JP274.9
!SS23: ATMEGA328P-AU23.14, JP286.9
!SS24: ATMEGA328P-AU24.14, JP298.9
!SS25: ATMEGA328P-AU25.14, JP310.9
!SS26: ATMEGA328P-AU26.14, JP322.9
!SS27: ATMEGA328P-AU27.14, JP334.9
!SS28: ATMEGA328P-AU28.14, JP346.9
!SS29: ATMEGA328P-AU29.14, JP358.9
A/COL: ATMEGA328P-AU.10, R2.2
A/COL1: ATMEGA328P-AU1.10, R11.2
A/COL2: ATMEGA328P-AU2.10, R20.2
A/COL3: ATMEGA328P-AU3.10, R29.2
A/COL4: ATMEGA328P-AU4.10, R38.2
A/COL5: ATMEGA328P-AU5.10, R47.2
A/COL6: ATMEGA328P-AU6.10, R56.2
A/COL7: ATMEGA328P-AU7.10, R65.2
A/COL8: ATMEGA328P-AU8.10, R74.2
A/COL9: ATMEGA328P-AU9.10, R83.2
A/COL10: ATMEGA328P-AU10.10, R92.2
A/COL11: ATMEGA328P-AU11.10, R101.2
A/COL12: ATMEGA328P-AU12.10, R110.2
A/COL13: ATMEGA328P-AU13.10, R119.2
A/COL14: ATMEGA328P-AU14.10, R128.2
A/COL15: ATMEGA328P-AU15.10, R137.2
A/COL16: ATMEGA328P-AU16.10, R146.2
A/COL17: ATMEGA328P-AU17.10, R155.2
A/COL18: ATMEGA328P-AU18.10, R164.2
A/COL19: ATMEGA328P-AU19.10, R173.2
A/COL20: ATMEGA328P-AU20.10, R182.2
A/COL21: ATMEGA328P-AU21.10, R191.2
A/COL22: ATMEGA328P-AU22.10, R200.2
A/COL23: ATMEGA328P-AU23.10, R209.2
A/COL24: ATMEGA328P-AU24.10, R218.2
A/COL25: ATMEGA328P-AU25.10, R227.2
A/COL26: ATMEGA328P-AU26.10, R236.2
A/COL27: ATMEGA328P-AU27.10, R245.2
A/COL28: ATMEGA328P-AU28.10, R254.2
A/COL29: ATMEGA328P-AU29.10, R263.2
ADC1: ATMEGA328P-AU1.19, JP22.2
ADC2: ATMEGA328P-AU1.22, JP22.1
ADC3: ATMEGA328P-AU2.19, JP34.2
ADC4: ATMEGA328P-AU2.22, JP34.1
ADC5: ATMEGA328P-AU3.19, JP46.2
ADC6: ATMEGA328P-AU.19, JP12.2
ADC7: ATMEGA328P-AU.22, JP12.1
ADC8: ATMEGA328P-AU3.22, JP46.1
ADC9: ATMEGA328P-AU4.19, JP58.2
ADC10: ATMEGA328P-AU4.22, JP58.1
ADC11: ATMEGA328P-AU5.19, JP70.2
ADC12: ATMEGA328P-AU5.22, JP70.1
ADC13: ATMEGA328P-AU6.19, JP82.2
ADC14: ATMEGA328P-AU6.22, JP82.1
ADC15: ATMEGA328P-AU7.19, JP94.2
ADC16: ATMEGA328P-AU7.22, JP94.1
ADC17: ATMEGA328P-AU8.19, JP106.2
ADC18: ATMEGA328P-AU8.22, JP106.1
ADC19: ATMEGA328P-AU9.19, JP118.2
ADC20: ATMEGA328P-AU9.22, JP118.1
ADC21: ATMEGA328P-AU10.19, JP130.2
ADC22: ATMEGA328P-AU10.22, JP130.1
ADC23: ATMEGA328P-AU11.19, JP142.2
ADC24: ATMEGA328P-AU11.22, JP142.1
ADC25: ATMEGA328P-AU12.19, JP154.2
ADC26: ATMEGA328P-AU12.22, JP154.1
ADC27: ATMEGA328P-AU13.19, JP166.2
ADC28: ATMEGA328P-AU13.22, JP166.1
ADC29: ATMEGA328P-AU14.19, JP178.2
ADC30: ATMEGA328P-AU14.22, JP178.1
ADC31: ATMEGA328P-AU15.19, JP190.2
ADC32: ATMEGA328P-AU15.22, JP190.1
ADC33: ATMEGA328P-AU16.19, JP202.2
ADC34: ATMEGA328P-AU16.22, JP202.1
ADC35: ATMEGA328P-AU17.19, JP214.2
ADC36: ATMEGA328P-AU17.22, JP214.1
ADC37: ATMEGA328P-AU18.19, JP226.2
ADC38: ATMEGA328P-AU18.22, JP226.1
ADC39: ATMEGA328P-AU19.19, JP238.2
ADC40: ATMEGA328P-AU19.22, JP238.1
ADC41: ATMEGA328P-AU20.19, JP250.2
ADC42: ATMEGA328P-AU20.22, JP250.1
ADC43: ATMEGA328P-AU21.19, JP262.2
ADC44: ATMEGA328P-AU21.22, JP262.1
ADC45: ATMEGA328P-AU22.19, JP274.2
ADC46: ATMEGA328P-AU22.22, JP274.1
ADC47: ATMEGA328P-AU23.19, JP286.2
ADC48: ATMEGA328P-AU23.22, JP286.1
ADC49: ATMEGA328P-AU24.19, JP298.2
ADC50: ATMEGA328P-AU24.22, JP298.1
ADC51: ATMEGA328P-AU25.19, JP310.2
ADC52: ATMEGA328P-AU25.22, JP310.1
ADC53: ATMEGA328P-AU26.19, JP322.2
ADC54: ATMEGA328P-AU26.22, JP322.1
ADC55: ATMEGA328P-AU27.19, JP334.2
ADC56: ATMEGA328P-AU27.22, JP334.1
ADC57: ATMEGA328P-AU28.19, JP346.2
ADC58: ATMEGA328P-AU28.22, JP346.1
ADC59: ATMEGA328P-AU29.19, JP358.2
ADC60: ATMEGA328P-AU29.22, JP358.1
APOSA: ATMEGA328P-AU.13, LED1.10
APOSA1: ATMEGA328P-AU1.13, LED2.10
APOSA2: ATMEGA328P-AU2.13, LED3.10
APOSA3: ATMEGA328P-AU3.13, LED4.10
APOSA4: ATMEGA328P-AU4.13, LED5.10
APOSA5: ATMEGA328P-AU5.13, LED6.10
APOSA6: ATMEGA328P-AU6.13, LED7.10
APOSA7: ATMEGA328P-AU7.13, LED8.10
APOSA8: ATMEGA328P-AU8.13, LED9.10
APOSA9: ATMEGA328P-AU9.13, LED10.10
APOSA10: ATMEGA328P-AU10.13, LED11.10
APOSA11: ATMEGA328P-AU11.13, LED12.10
APOSA12: ATMEGA328P-AU12.13, LED13.10
APOSA13: ATMEGA328P-AU13.13, LED14.10
APOSA14: ATMEGA328P-AU14.13, LED15.10
APOSA15: ATMEGA328P-AU15.13, LED16.10
APOSA16: ATMEGA328P-AU16.13, LED17.10
APOSA17: ATMEGA328P-AU17.13, LED18.10
APOSA18: ATMEGA328P-AU18.13, LED19.10
APOSA19: ATMEGA328P-AU19.13, LED20.10
APOSA20: ATMEGA328P-AU20.13, LED21.10
APOSA21: ATMEGA328P-AU21.13, LED22.10
APOSA22: ATMEGA328P-AU22.13, LED23.10
APOSA23: ATMEGA328P-AU23.13, LED24.10
APOSA24: ATMEGA328P-AU24.13, LED25.10
APOSA25: ATMEGA328P-AU25.13, LED26.10
APOSA26: ATMEGA328P-AU26.13, LED27.10
APOSA27: ATMEGA328P-AU27.13, LED28.10
APOSA28: ATMEGA328P-AU28.13, LED29.10
APOSA29: ATMEGA328P-AU29.13, LED30.10
B: ATMEGA328P-AU.12, R3.2
B1: ATMEGA328P-AU1.12, R12.2
B2: ATMEGA328P-AU2.12, R21.2
B3: ATMEGA328P-AU3.12, R30.2
B4: ATMEGA328P-AU4.12, R39.2
B5: ATMEGA328P-AU5.12, R48.2
B6: ATMEGA328P-AU6.12, R57.2
B7: ATMEGA328P-AU7.12, R66.2
B8: ATMEGA328P-AU8.12, R75.2
B9: ATMEGA328P-AU9.12, R84.2
B10: ATMEGA328P-AU10.12, R93.2
B11: ATMEGA328P-AU11.12, R102.2
B12: ATMEGA328P-AU12.12, R111.2
B13: ATMEGA328P-AU13.12, R120.2
B14: ATMEGA328P-AU14.12, R129.2
B15: ATMEGA328P-AU15.12, R138.2
B16: ATMEGA328P-AU16.12, R147.2
B17: ATMEGA328P-AU17.12, R156.2
B18: ATMEGA328P-AU18.12, R165.2
B19: ATMEGA328P-AU19.12, R174.2
B20: ATMEGA328P-AU20.12, R183.2
B21: ATMEGA328P-AU21.12, R192.2
B22: ATMEGA328P-AU22.12, R201.2
B23: ATMEGA328P-AU23.12, R210.2
B24: ATMEGA328P-AU24.12, R219.2
B25: ATMEGA328P-AU25.12, R228.2
B26: ATMEGA328P-AU26.12, R237.2
B27: ATMEGA328P-AU27.12, R246.2
B28: ATMEGA328P-AU28.12, R255.2
B29: ATMEGA328P-AU29.12, R264.2
C: ATMEGA328P-AU.23, R4.2
C1: ATMEGA328P-AU1.23, R13.2
C2: ATMEGA328P-AU2.23, R22.2
C3: ATMEGA328P-AU3.23, R31.2
C4: ATMEGA328P-AU4.23, R40.2
C5: ATMEGA328P-AU5.23, R49.2
C6: ATMEGA328P-AU6.23, R58.2
C7: ATMEGA328P-AU7.23, R67.2
C8: ATMEGA328P-AU8.23, R76.2
C9: ATMEGA328P-AU9.23, R85.2
C10: ATMEGA328P-AU10.23, R94.2
C11: ATMEGA328P-AU11.23, R103.2
C12: ATMEGA328P-AU12.23, R112.2
C13: ATMEGA328P-AU13.23, R121.2
C14: ATMEGA328P-AU14.23, R130.2
C15: ATMEGA328P-AU15.23, R139.2
C16: ATMEGA328P-AU16.23, R148.2
C17: ATMEGA328P-AU17.23, R157.2
C18: ATMEGA328P-AU18.23, R166.2
C19: ATMEGA328P-AU19.23, R175.2
C20: ATMEGA328P-AU20.23, R184.2
C21: ATMEGA328P-AU21.23, R193.2
C22: ATMEGA328P-AU22.23, R202.2
C23: ATMEGA328P-AU23.23, R211.2
C24: ATMEGA328P-AU24.23, R220.2
C25: ATMEGA328P-AU25.23, R229.2
C26: ATMEGA328P-AU26.23, R238.2
C27: ATMEGA328P-AU27.23, R247.2
C28: ATMEGA328P-AU28.23, R256.2
C29: ATMEGA328P-AU29.23, R265.2
COLA: ATMEGA328P-AU.32, LED1.4
COLA1: ATMEGA328P-AU1.32, LED2.4
COLA2: ATMEGA328P-AU2.32, LED3.4
COLA3: ATMEGA328P-AU3.32, LED4.4
COLA4: ATMEGA328P-AU4.32, LED5.4
COLA5: ATMEGA328P-AU5.32, LED6.4
COLA6: ATMEGA328P-AU6.32, LED7.4
COLA7: ATMEGA328P-AU7.32, LED8.4
COLA8: ATMEGA328P-AU8.32, LED9.4
COLA9: ATMEGA328P-AU9.32, LED10.4
COLA10: ATMEGA328P-AU10.32, LED11.4
COLA11: ATMEGA328P-AU11.32, LED12.4
COLA12: ATMEGA328P-AU12.32, LED13.4
COLA13: ATMEGA328P-AU13.32, LED14.4
COLA14: ATMEGA328P-AU14.32, LED15.4
COLA15: ATMEGA328P-AU15.32, LED16.4
COLA16: ATMEGA328P-AU16.32, LED17.4
COLA17: ATMEGA328P-AU17.32, LED18.4
COLA18: ATMEGA328P-AU18.32, LED19.4
COLA19: ATMEGA328P-AU19.32, LED20.4
COLA20: ATMEGA328P-AU20.32, LED21.4
COLA21: ATMEGA328P-AU21.32, LED22.4
COLA22: ATMEGA328P-AU22.32, LED23.4
COLA23: ATMEGA328P-AU23.32, LED24.4
COLA24: ATMEGA328P-AU24.32, LED25.4
COLA25: ATMEGA328P-AU25.32, LED26.4
COLA26: ATMEGA328P-AU26.32, LED27.4
COLA27: ATMEGA328P-AU27.32, LED28.4
COLA28: ATMEGA328P-AU28.32, LED29.4
COLA29: ATMEGA328P-AU29.32, LED30.4
D: ATMEGA328P-AU.24, R6.2
D1: ATMEGA328P-AU1.24, R14.2
D2: ATMEGA328P-AU2.24, R23.2
D3: ATMEGA328P-AU3.24, R32.2
D4: ATMEGA328P-AU4.24, R41.2
D5: ATMEGA328P-AU5.24, R50.2
D6: ATMEGA328P-AU6.24, R59.2
D7: ATMEGA328P-AU7.24, R68.2
D8: ATMEGA328P-AU8.24, R77.2
D9: ATMEGA328P-AU9.24, R86.2
D10: ATMEGA328P-AU10.24, R95.2
D11: ATMEGA328P-AU11.24, R104.2
D12: ATMEGA328P-AU12.24, R113.2
D13: ATMEGA328P-AU13.24, R122.2
D14: ATMEGA328P-AU14.24, R131.2
D15: ATMEGA328P-AU15.24, R140.2
D16: ATMEGA328P-AU16.24, R149.2
D17: ATMEGA328P-AU17.24, R158.2
D18: ATMEGA328P-AU18.24, R167.2
D19: ATMEGA328P-AU19.24, R176.2
D20: ATMEGA328P-AU20.24, R185.2
D21: ATMEGA328P-AU21.24, R194.2
D22: ATMEGA328P-AU22.24, R203.2
D23: ATMEGA328P-AU23.24, R212.2
D24: ATMEGA328P-AU24.24, R221.2
D25: ATMEGA328P-AU25.24, R230.2
D26: ATMEGA328P-AU26.24, R239.2
D27: ATMEGA328P-AU27.24, R248.2
D28: ATMEGA328P-AU28.24, R257.2
D29: ATMEGA328P-AU29.24, R266.2
DIG1: ATMEGA328P-AU.25, LED1.1
DIG2: ATMEGA328P-AU.26, LED1.2
DIG3: ATMEGA328P-AU.1, LED1.6
DIG4: ATMEGA328P-AU.2, LED1.8
DIG5: ATMEGA328P-AU1.2, LED2.8
DIG6: ATMEGA328P-AU1.1, LED2.6
DIG7: ATMEGA328P-AU1.26, LED2.2
DIG8: ATMEGA328P-AU1.25, LED2.1
DIG9: ATMEGA328P-AU2.2, LED3.8
DIG10: ATMEGA328P-AU2.1, LED3.6
DIG11: ATMEGA328P-AU2.26, LED3.2
DIG12: ATMEGA328P-AU2.25, LED3.1
DIG13: ATMEGA328P-AU3.2, LED4.8
DIG14: ATMEGA328P-AU3.1, LED4.6
DIG15: ATMEGA328P-AU3.26, LED4.2
DIG16: ATMEGA328P-AU3.25, LED4.1
DIG17: ATMEGA328P-AU4.2, LED5.8
DIG18: ATMEGA328P-AU4.1, LED5.6
DIG19: ATMEGA328P-AU4.26, LED5.2
DIG20: ATMEGA328P-AU4.25, LED5.1
DIG21: ATMEGA328P-AU5.2, LED6.8
DIG22: ATMEGA328P-AU5.1, LED6.6
DIG23: ATMEGA328P-AU5.26, LED6.2
DIG24: ATMEGA328P-AU5.25, LED6.1
DIG25: ATMEGA328P-AU6.2, LED7.8
DIG26: ATMEGA328P-AU6.1, LED7.6
DIG27: ATMEGA328P-AU6.26, LED7.2
DIG28: ATMEGA328P-AU6.25, LED7.1
DIG29: ATMEGA328P-AU7.2, LED8.8
DIG30: ATMEGA328P-AU7.1, LED8.6
DIG31: ATMEGA328P-AU7.26, LED8.2
DIG32: ATMEGA328P-AU7.25, LED8.1
DIG33: ATMEGA328P-AU8.2, LED9.8
DIG34: ATMEGA328P-AU8.1, LED9.6
DIG35: ATMEGA328P-AU8.26, LED9.2
DIG36: ATMEGA328P-AU8.25, LED9.1
DIG37: ATMEGA328P-AU9.2, LED10.8
DIG38: ATMEGA328P-AU9.1, LED10.6
DIG39: ATMEGA328P-AU9.26, LED10.2
DIG40: ATMEGA328P-AU9.25, LED10.1
DIG41: ATMEGA328P-AU10.2, LED11.8
DIG42: ATMEGA328P-AU10.1, LED11.6
DIG43: ATMEGA328P-AU10.26, LED11.2
DIG44: ATMEGA328P-AU10.25, LED11.1
DIG45: ATMEGA328P-AU11.2, LED12.8
DIG46: ATMEGA328P-AU11.1, LED12.6
DIG47: ATMEGA328P-AU11.26, LED12.2
DIG48: ATMEGA328P-AU11.25, LED12.1
DIG49: ATMEGA328P-AU12.2, LED13.8
DIG50: ATMEGA328P-AU12.1, LED13.6
DIG51: ATMEGA328P-AU12.26, LED13.2
DIG52: ATMEGA328P-AU12.25, LED13.1
DIG53: ATMEGA328P-AU13.2, LED14.8
DIG54: ATMEGA328P-AU13.1, LED14.6
DIG55: ATMEGA328P-AU13.26, LED14.2
DIG56: ATMEGA328P-AU13.25, LED14.1
DIG57: ATMEGA328P-AU14.2, LED15.8
DIG58: ATMEGA328P-AU14.1, LED15.6
DIG59: ATMEGA328P-AU14.26, LED15.2
DIG60: ATMEGA328P-AU14.25, LED15.1
DIG61: ATMEGA328P-AU15.2, LED16.8
DIG62: ATMEGA328P-AU15.1, LED16.6
DIG63: ATMEGA328P-AU15.26, LED16.2
DIG64: ATMEGA328P-AU15.25, LED16.1
DIG65: ATMEGA328P-AU16.2, LED17.8
DIG66: ATMEGA328P-AU16.1, LED17.6
DIG67: ATMEGA328P-AU16.26, LED17.2
DIG68: ATMEGA328P-AU16.25, LED17.1
DIG69: ATMEGA328P-AU17.2, LED18.8
DIG70: ATMEGA328P-AU17.1, LED18.6
DIG71: ATMEGA328P-AU17.26, LED18.2
DIG72: ATMEGA328P-AU17.25, LED18.1
DIG73: ATMEGA328P-AU18.2, LED19.8
DIG74: ATMEGA328P-AU18.1, LED19.6
DIG75: ATMEGA328P-AU18.26, LED19.2
DIG76: ATMEGA328P-AU18.25, LED19.1
DIG77: ATMEGA328P-AU19.2, LED20.8
DIG78: ATMEGA328P-AU19.1, LED20.6
DIG79: ATMEGA328P-AU19.26, LED20.2
DIG80: ATMEGA328P-AU19.25, LED20.1
DIG81: ATMEGA328P-AU20.2, LED21.8
DIG82: ATMEGA328P-AU20.1, LED21.6
DIG83: ATMEGA328P-AU20.26, LED21.2
DIG84: ATMEGA328P-AU20.25, LED21.1
DIG85: ATMEGA328P-AU21.2, LED22.8
DIG86: ATMEGA328P-AU21.1, LED22.6
DIG87: ATMEGA328P-AU21.26, LED22.2
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

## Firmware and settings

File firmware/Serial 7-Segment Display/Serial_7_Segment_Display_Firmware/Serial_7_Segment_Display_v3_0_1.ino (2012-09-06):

/* Serial 7 Segment Display Firmware
   Version: 3.0.1
   By: Jim Lindblom (SparkFun Electronics)
   Date: August 24, 2012
   License: This code is beerware: feel free to use it, with or without attribution,
   in your own projects. If you find it helpful, buy me a beer next time you see me
   at the local.
   
   Description: This firmware goes on the SparkFun Serial 7-Segment displays.
   !!! Add product page link
   You can send the display serial data over either UART, SPI, or I2C. It'll
   sequentially display what it reads. There are special commands to control 
   individual segments, clear the display, reset the cursor, adjust the display's 
   brightness, UART baud rate, i2c address or factory reset.
   
   Arduino addon: This code should remain with the Serial7Seg Arduino hardware
   addon. New pin defines are required for pins 22 and 23 - PB6:7. Because the
   Serial 7-Segment runs on the ATmega328's internal oscillator, these two pins
   open up for our use.

   Hardware: You can find the Serial 7-Segment Display Schematic here:
   !!! Add schematic link
   
*/
#include <Wire.h>  // Handles I2C
#include <EEPROM.h>  // Brightness, Baud rate, and I2C address are stored in EEPROM
#include "settings.h"  // Defines command bytes, EEPROM addresses, display data

/* Digit Defines 
   Used with cathodes[] array (below) to reference specific segments */
const int A_SEG = 0;
const int B_SEG = 1;
const int C_SEG = 2;
const int D_SEG = 3;
const int E_SEG = 4;
const int F_SEG = 5;
const int G_SEG = 6;
const int DP_SEG = 7;

/* Pin defines for LED anodes and cathodes */
const byte anodes[6] = {A2, A3, 3, 4, 2, 9};  // Dig0, Dig1, Dig2, Dig3, Colon, Apostrophe
const byte cathodes[8] = {8, A0, 6, A1, 23, 7, 5, 22};  // A, B, C, D, E, F, G, DP
//const byte cathodes[8] = {6, 8, A0, A1, 23, 7, 5, 22};  // A, B, C, D, E, F, G, DP

/* Struct for circular data buffer
   data received over UART, SPI and I2C are all sent into a single buffer */
struct dataBuffer
{
  unsigned char data[BUFFER_SIZE];  // THE data buffer
  unsigned int head;  // store new data at this index
  unsigned int tail;  // read oldest data from this index
} buffer;  // our data buffer is creatively named - buffer

unsigned char commandMode = 0;  // Used to indicate if a commandMode byte has been received

/* Struct for 4-digit, 7-segment display 
   Stores display value (digits),  decimal status (decimals) for each digit, 
   and cursor for overall display */
struct display
{
  unsigned char digits[4];
  unsigned char decimals;
  unsigned char cursor;
} display;  // displays be displays

/* displayPeriod conrols the brightness of the display 
   it controls how long in microseconds a display will be active  */
const int displayPeriodMax = 10000;  //microseconds - how long to run through one cycle of display PWM
int displayPeriod = 2000;  // microseconds, maximum of 3000 - length of time each digit on display is active

/* SPI byte received interrupt routine */
ISR(SPI_STC_vect)
{
  noInterrupts();  // don't be rude! I'll be quick...
  
  unsigned int i = (buffer.head + 1) % BUFFER_SIZE;  // read buffer head position and increment
  unsigned char c = SPDR;  // Read data byte into c, from SPI data register
  
  if (i != buffer.tail)  // As long as the buffer isn't full, we can store the data in buffer
  {
    buffer.data[buffer.head] = c;  // Store the data into the buffer's head
    buffer.head = i;  // update buffer head, since we stored new data
  }
  
  interrupts();  // Fine, you were saying?
}

/* UART0 byte received interrupt routine */
ISR(USART_RX_vect)
{
  noInterrupts();  // We'll be quick...
  
  unsigned int i = (buffer.head + 1) % BUFFER_SIZE;  // read buffer head position and increment
  unsigned char c = UDR0;  // Read data byte into c, from UART0 data register
  
  if (i != buffer.tail)  // As long as the buffer isn't full, we can store the data in buffer
  {
    buffer.data[buffer.head] = c;  // Store the data into the buffer's head
    buffer.head = i;  // update buffer head, since we stored new data
  }
  
  interrupts();  // Okay, resume interrupts
}

/* I2C byte receive interrupt routine
   Note: this isn't an ISR. I'm using wire library (because it just works), so
   Wire.onReceive(twiReceive); should be called */
void twiReceive(int rxCount)
{
  while(Wire.available() > 0)  // Do this while data is available in Wire buffer
  {
    unsigned int i = (buffer.head + 1) % BUFFER_SIZE;  // read buffer head position and increment
    unsigned char c = Wire.read();  // Read data byte into c, from Wire data buffer
    
    if (i != buffer.tail)  // As long as the buffer isn't full, we can store the data in buffer
    {
      buffer.data[buffer.head] = c;  // Store the data into the buffer's head
      buffer.head = i;  // update buffer head, since we stored new data
    }    
  }
}

/* The display data is updated on a Timer interrupt */
ISR(TIMER1_COMPA_vect)
{
  noInterrupts();
  
  // if head and tail are not equal, there's data to be read from the buffer
  if (buffer.head != buffer.tail)
    updateBufferData();  // updateBufferData() will update the display info, or peform special commands
    
  interrupts();
}

void setup()
{  
  pinMode(10, OUTPUT);
  digitalWrite(10, LOW);
  delayMicroseconds(1);
  pinMode(10, INPUT_PULLUP);
  
  /* Set the initial state of displays and decimals 'x' =  off */
  display.digits[0] = 'x';
  display.digits[1] = 'x';
  display.digits[2] = 'x';
  display.digits[3] = 'x';
  display.decimals = 0x00;  // Turn all decimals off
  
  display.cursor = 0;  // Set cursor to first (left-most) digit
  buffer.head = 0;  // Initialize buffer values
  buffer.tail = 0;  
  
  /* Initialize anode pin states to OUTPUTS, all LOWs */
  for (int i=0; i<6; i++)
  {
    pinMode(anodes[i], OUTPUT);
    digitalWrite(anodes[i], LOW);
  }
  
  /* Initialize cathode pin states to OUTPUTS all HIGHs */
  for (int i=0; i<8; i++)
  {
    pinMode(cathodes[i], OUTPUT);
    digitalWrite(cathodes[i], HIGH);
  }
  
  /* displayPeriod controls the brightness of our display
     read the brightness value from EEPROM and map the 0 */
  displayPeriod = map(EEPROM.read(BRIGHTNESS_ADDRESS), 0, 255, 0, 2000);
  
  setupTimer();  // Setup timer to control interval reading from buffer
  setupUart();   // initialize UART stuff (interrupts, enable, baud)
  setupSPI();    // Initialize SPI stuff (enable, mode, interrupts)
  setupTWI();    // Initialize I2C stuff (address, interrupt, enable)
    
  interrupts();  // Turn interrupts on, and les' go
}

/* The display is constantly PWM'd in the loop() */
void loop()
{
  int delayTimer = 0;
  
  for (int i=0; i<5; i++)  // Run through this once for each digit and once for the decimals
  {
    displayDigit(display.digits[i], i);  // Set all the segments correctly
    
    delayMicroseconds(displayPeriod+1);  // Blocking delay while the digit is on
  }
  
  clearDisplay();  // Clear the display, this is how we adjust brightness
  /* delay for whats left of our maximum displayPeriod */
  delayMicroseconds((displayPeriodMax - 5 * displayPeriod) + 1); 
}

/* updateBufferData(): This beast of a function is called by the Timer 1 ISR if there is
   new data in the buffer. 
   If the data controls display data, that'll be updated.
   If the data relates to a command, commandmode will be set accordingly or a command 
   will be executed from this function. */
void updateBufferData()
{
  /* First we read from the oldest data in the buffer  */
  unsigned char c = buffer.data[buffer.tail];
  buffer.tail = (buffer.tail + 1) % BUFFER_SIZE;  // and update the tail to the next oldest
  
  /* if the last byte received wasn't a command byte (commandMode=0)
     and if the data is displayable (0-0x76 or 0x78), the display will be updated*/
  if ((commandMode == 0) && ((c < 0x76) || (c == 0x78)))
  {
    display.digits[display.cursor] = c;  // just store the read data into the cursor-active digit
    display.cursor = ((display.cursor + 1) % 4);  // Increment cursor, set back to 0 if necessary
  }
  else if (c == RESET_CMD)  // If the received char is the reset command
  {
    for (int i=0; i<4; i++)
      display.digits[i] = 'x';  // clear all digits
    display.decimals = 0;  // clear all decimals
    display.cursor = 0;  // reset the cursor
  }
  else if (commandMode != 0)  // Otherwise, if data is non-displayable and we're in a commandMode
  {
    unsigned int baud = 103;  // Default to 9600 if non-usable data received
    
    switch (commandMode)
    {
      case DECIMAL_CMD:  // Decimal setting mode
        display.decimals = c;  // decimals are set by one byte
        break;
      case BRIGHTNESS_CMD:  // Brightness setting mode
        displayPeriod = map(c, 0, 255, 0, 2000);  // Adjust the amount of time digits are on
        EEPROM.write(BRIGHTNESS_ADDRESS, c);    // write the new value to EEPROM
        break;
      case BAUD_CMD:  // Baud setting mode 
        switch (c)
        {
          case 0: // 2400
            baud = 416;
            break;
          case 1:  // 4800
            baud = 207;
            break;
          case 2:  // 9600
            baud = 103;
            break;
          case 3:  // 14400
            baud = 68;
            break;
          case 4:  // 19200
            baud = 51;
            break;
          case 5:  // 38400
            baud = 25;
            break;
          case 6:  // 57600
            baud = 16;
            break;
          case 7:  // 76800
            baud = 12;
            break;
          case 8:  // 115200
            baud = 8;
            break;
          case 9:  // 250000
            baud = 3;
            break;
          case 10:  // 500000
            baud = 1;
            break;
          case 11:  // 1000000
            baud = 0;
            break;
        }
        UBRR0 = baud;  // UBRR0 is set with no regard to F_CPU, assuming 8MHz 2x speed
        EEPROM.write(BAUD_ADDRESS_H, (unsigned char)(baud>>8));  // Update EEPROM baud setting
        EEPROM.write(BAUD_ADDRESS_L, (unsigned char)(baud & 0xFF));
        break;
      case CURSOR_CMD:  // Set the cursor
        if (c <= 3)  // Limited error checking, if >3 cursor command will have no effect
          display.cursor = c;  // Update the cursor value
        break;
      case TWI_ADDRESS_CMD:  // Set the I2C Address
        if ((c > 0) && (c < 0x7F))  
        { // As long as the address value is valid msb can't be set, can't be 0 (general call)
          EEPROM.write(TWI_ADDRESS_ADDRESS, c);  // Update the EEPROM value
          Wire.begin(c);  // on-the fly I2C address update
        }
        break;
      case FACTORY_RESET_CMD:  // Factory reset
        factoryReset();  // Let's do that in a function
        break;
      case DIGIT1_CMD:  // Single-digit control for digit 1
        display.digits[0] = c | 0x80;  // set msb to indicate single digit control mode
        break;
      case DIGIT2_CMD:  // Single-digit control for digit 2
        display.digits[1] = c | 0x80;
        break;
      case DIGIT3_CMD:  // Single-digit control for digit 3
        display.digits[2] = c | 0x80;
        break;
      case DIGIT4_CMD:  // Single-digit control for digit 4
        display.digits[3] = c | 0x80;
        break;
    }
    /* Leaving commandMode 
      !!! If the commandMode isn't a valid command, we'll leave command mode, should be checked below? */
    commandMode = 0;
  }
  else  // Finally, if we weren't in command mode, if the byte isn't displayable, we'll enter command mode
  {
    commandMode = c;  // which command mode is reflected by value of commandMode
  }
}

/* seutpTimer(): Set up timer 1, which controls interval reading from the buffer */
void setupTimer()
{
  /* Timer 1 is se to CTC mode, 16-bit timer counts up to 0xFF */
  TCCR1B = (1<<WGM12) | (1<<CS10);
  OCR1A = 0x00FF;
  TIMSK1 = (1<<OCIE1A);  // Enable interrupt on compare
}

/* setupUart(): Initializes UART0 hardware pins, sets up UART interrupt 
   Sets baud rate, parity, stop bit and data bits */
void setupUart()
{
  pinMode(0, INPUT);  // RX set as an INPUT
  
  UCSR0A = (1<<U2X0);  // DOUBLE SPEEEEEEED!
  UCSR0B = (1<<RXCIE0) | (1<<RXEN0);   // Enable RX, RX complete interrupt
  UCSR0C = (1<<UCSZ01) | (1<<UCSZ00);  // Asynchronous, no parity, 1 stop bit, 8 bit
  
  //EEPROM.write(BAUD_ADDRESS_L, 0xFF);  // These are useful if you need to reset...
  //EEPROM.write(BAUD_ADDRESS_H, 0xFF);  // ...the baud rate values in EEPROM
  
  /* read the baud rate setting from EEPROM */
  unsigned int baud = (EEPROM.read(BAUD_ADDRESS_H)<<8) | EEPROM.read(BAUD_ADDRESS_L);
  
  /* Check if the baud rate setting is valid */
  if ((baud==416)||(baud==207)||(baud==103)||(baud==68)||(baud==51)||(baud==34)
      ||(baud==25)||(baud==16)||(baud==12)||(baud==8)||(baud==3)||(baud==1)||(baud==0))
  {
    UBRR0 = baud;  // and update the UBRR0 !!! This is dependent on double-speed and 8MHz clock
  }
  else  // if the baud rate setting was invalid, default to 9600
  {
    baud = 103;  // !!! dependent on 8MHz, double speed uart
    UBRR0 = baud;  // default to 9600
    EEPROM.write(BAUD_ADDRESS_L, baud);  // Update EEPROM to reflect 9600 buad
    EEPROM.write(BAUD_ADDRESS_H, 0);
  }
}

/* setupSPI(): Initialize SPI, sets up hardware pins and enables spi and receive interrupt
   SPI is set to MODE 0 (CPOL=0, CPHA=0), slave mode, LSB first */
void setupSPI()
{
  pinMode(13, INPUT);  // SCK
  pinMode(11, INPUT);  // MOSI
  pinMode(10, INPUT_PULLUP);  // SS
  
  SPCR = (1<<SPIE) | (1<<SPE);  // Enable SPI interrupt, enable SPI
  /* DORD = 0, LSB First
     MSTR = 0, SLAVE
     CPOL = 0, sck low when idle                  } MODE 0
     CPHA = 0, data sampled on leading clock edge } MODE 0
     SPR1:0 = 0, no effect (slave mode) */
}

/* setupTWI(): initializes I2C (err TWI! TWI! TWI!, can't bang that into my head enough)
   I'm using the rock-solid Wire library for this. We'll initialize TWI, setup the address,
   and tell it what interrupt function to jump to when data is received. */
void setupTWI()
{
  unsigned char twiAddress;
  
  twiAddress = EEPROM.read(TWI_ADDRESS_ADDRESS);  // read the TWI address from 
  
  if ((twiAddress == 0) || (twiAddress > 0x7F))  
  { // If the TWI address is invalid, use a default address
    twiAddress = TWI_ADDRESS_DEFAULT;
    EEPROM.write(TWI_ADDRESS_ADDRESS, TWI_ADDRESS_DEFAULT);
  }
  
  Wire.begin(twiAddress);  // Initialize Wire library as slave at twiAddress address
  Wire.onReceive(twiReceive);  // setup interrupt routine for when data is received
}

/* factoryReset(): Uhoh! If something breaks, try sending a factory reset command to the device
   This will reset baud, TWI address, and brightness to default values */
void factoryReset()
{
  /* Reset Baud (9600) */
  unsigned int baud = BAUD_DEFAULT;
  UBRR0 = baud;
  EEPROM.write(BAUD_ADDRESS_L, (unsigned char)(baud & 0xFF));
  EEPROM.write(BAUD_ADDRESS_H, (unsigned char)(baud >> 8));
  
  
  /* Reset TWI Address (0x71) */
  Wire.begin(TWI_ADDRESS_DEFAULT);
  EEPROM.write(TWI_ADDRESS_ADDRESS, TWI_ADDRESS_DEFAULT);
  
  /* Reset Brightness (FULL BRIGHNESS!) */
  displayPeriod = map(255, 0, 255, 0, 2000);
  EEPROM.write(BRIGHTNESS_ADDRESS, BRIGHTNESS_DEFAULT);
  
}

/* displayDigit(byte number, byte digit): Displays number on digit.
   This function actually displays stuff. It sets the anodes to turn activate a digit,
   and it sets the cathodes to turn on the proper segments. It'll decode 0-F and ASCII
   e.g. displayDigit(8, 0) makes the left-most digit display '8'.
   displayDigit('b', 3) displays 'b' on 3. 
   if digit=4, the colon and apostrophes are controlled */
void displayDigit(byte number, byte digit)
{
  clearDisplay();  // Clear the display
  digitalWrite(anodes[digit], HIGH);  // pull the proper anode HIGH
      
  if (digit == 4)  // if digit=4, the colon and apostrophe are being controlled
  {
    digitalWrite(anodes[5], HIGH);  // We'll also need to activate the apostrophe anode
    if ((display.decimals & (1<<4)))  // Turn the colon on if bit set
      digitalWrite(6, LOW);  // Colon cathode is shared with A segment cathode
    if ((display.decimals & (1<<5)))  // Turn the apostrophe on if bit set
      digitalWrite(7, LOW);  // Apostrophe cathode shared with F segment cathode
  }
  else  // otherwise digit should be 0-3
  {
    if (number & 0x80)  // If msb is set, we're in single-digit control mode for this digit
    {
      for (int i=0; i<7; i++)  // in single digit control mode ASCII isn't decode, bit-for-segment control
      {
        if (number & (1<<i))  // if a bit is set
          digitalWrite(cathodes[i], LOW);  // turn on the corresponding segment
      }
    }
    else  // otherwise, we need to decode the ASCII or value of number before it's displayed
    {
      for (int i=0; i<7; i++)
      {
        // displayArray (defined in settings.h) decides which segments are turned on for each value of number
        if (displayArray[number][i])
          digitalWrite(cathodes[i], LOW);  // if the bit is set, turn on that segment
      }
    }
    /* finally, if the decimal bit for this digit is set, turn on the DP */
    if ((display.decimals & (1<<digit)))
      digitalWrite(cathodes[DP_SEG], LOW);
  }
}

/* clearDisplay(): Turns off everything! */
void clearDisplay()
{
  for (int i=0; i<6; i++)
    digitalWrite(anodes[i], LOW);  // anodes LOW
    
  for (int i=0; i<8; i++)
  {
    digitalWrite(cathodes[i], HIGH);  // cathodes HIGH
  }
}

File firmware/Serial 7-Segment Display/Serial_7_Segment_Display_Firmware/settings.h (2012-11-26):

//Pin definitions
#define SPI_CS			10
#define SPI_MOSI		11
#define SPI_MISO		12
#define SPI_SCK			13

//Define the different baud rate levels
#define BAUD_2400	0
#define BAUD_4800	1
#define BAUD_9600	2
#define BAUD_14400	3
#define BAUD_19200	4
#define BAUD_38400	5
#define BAUD_57600	6
#define BAUD_76800	7
#define BAUD_115200	8
#define BAUD_250000	9
#define BAUD_500000	10
#define BAUD_1000000	11

//Bit locations for the decimal, apostrophe and colon control
//From https://github.com/sparkfun/Serial7SegmentDisplay/wiki/Special-Commands#wiki-decimal
#define APOSTROPHE  5
#define COLON       4
#define DECIMAL4    3
#define DECIMAL3    2
#define DECIMAL2    1
#define DECIMAL1    0

#define MODE_DATA    0
#define MODE_ANALOG  1
#define MODE_COUNTER 2

const int TWI_ADDRESS_DEFAULT = 0x71;
const int BAUD_DEFAULT  = BAUD_9600;  // 9600 for 8MHz, 2x speed
const int BRIGHTNESS_DEFAULT = 100;  // 100%, full brightness
const int MODE_DEFAULT = MODE_DATA; // Watch for incoming data rather than pulses or analog voltages

//Internal EEPROM locations for the user settings
const unsigned char BRIGHTNESS_ADDRESS = 0;
const unsigned char BAUD_ADDRESS = 1;
const unsigned char TWI_ADDRESS_ADDRESS = 2;
const unsigned char MODE_ADDRESS = 3;

/* Command Modes */
const unsigned char RESET_CMD         = 0x76;
const unsigned char DECIMAL_CMD       = 0x77;
const unsigned char BLANK_CMD         = 0x78;  // 'x'
const unsigned char CURSOR_CMD        = 0x79;  // !!! NEW
const unsigned char BRIGHTNESS_CMD    = 0x7A;  // !!! NEW functionality
const unsigned char DIGIT1_CMD        = 0x7B;
const unsigned char DIGIT2_CMD        = 0x7C;
const unsigned char DIGIT3_CMD        = 0x7D;
const unsigned char DIGIT4_CMD        = 0x7E;
const unsigned char BAUD_CMD          = 0x7F;
const unsigned char TWI_ADDRESS_CMD   = 0x80;  // !!! NEW
const unsigned char FACTORY_RESET_CMD = 0x81;  // !!! NEW
const unsigned char MODE_CMD          = 0x82;  // !!! NEW

const int BUFFER_SIZE = 64;

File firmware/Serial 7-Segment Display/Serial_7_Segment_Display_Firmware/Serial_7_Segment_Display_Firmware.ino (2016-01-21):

/* Serial 7 Segment Display Firmware
 Version: 3.0.1
 By: Jim Lindblom (SparkFun Electronics)
 Date: August 24, 2012
 License: This code is beerware: feel free to use it, with or without attribution,
 in your own projects. If you find it helpful, buy me a beer next time you see me
 at the local pub.
 
 Description: This firmware goes on the SparkFun Serial 7-Segment displays.
 https://www.sparkfun.com/search/results?term=serial+7+segment&what=products
 
 You can send the display serial data over either UART, SPI, or I2C. It'll
 sequentially display what it reads. There are special commands to control 
 individual segments, clear the display, reset the cursor, adjust the display's 
 brightness, UART baud rate, i2c address or factory reset.
 
 Note: To use the additional pins, PB6 and PB7, on the ATmega328 we have to add 
 some maps to the pins_arduino.h file. This allows Arduino to identify PB6 as 
 digital pin 22, and PB7 as digital pin 23. Because the Serial 7-Segment runs on 
 the ATmega328's internal oscillator, these two pins open up for our use.
 
 */
#include <Wire.h>  // Handles I2C
#include <EEPROM.h>  // Brightness, Baud rate, and I2C address are stored in EEPROM
#include "settings.h"  // Defines command bytes, EEPROM addresses, display data
// This code uses the SevSeg library, which can be donwnloaded from:
// https://github.com/sparkfun/SevSeg
#include "SevSeg.h" //Library to control generic seven segment displays

SevSeg myDisplay; //Create an instance of the object

//This firmware works on three different hardware layouts
//Serial7Segment was the original and drives the segments directly from the ATmega
//OpenSegment uses PNP and NPN transistors to drive larger displays
//Serial7SegmentShield also drives the segments directly from the ATmega
#define S7S            1
#define OPENSEGMENT    2
#define S7SHIELD       3
#define DISPLAY_TYPE OPENSEGMENT

//Global variables
unsigned int analogValue6 = 0; //These are used in analog meter mode
unsigned int analogValue7 = 0;
unsigned char deviceMode; // This variable is useds to select which mode the device should be in
unsigned char commandMode = 0;  // Used to indicate if a commandMode byte has been received

// Struct for circular data buffer data received over UART, SPI and I2C are all sent into a single buffer
struct dataBuffer
{
  unsigned char data[BUFFER_SIZE];  // THE data buffer
  unsigned int head;  // store new data at this index
  unsigned int tail;  // read oldest data from this index
} 
buffer;  // our data buffer is creatively named - buffer

// Struct for 4-digit, 7-segment display 
// Stores display value (digits),  decimal status (decimals) for each digit, and cursor for overall display
struct display
{
  char digits[4];
  unsigned char decimals;
  unsigned char cursor;
} 
display;  // displays be displays

void setup()
{  
  setupDisplay(); //Initialize display stuff (common cathode, digits, brightness, etc)

  //We need to check emergency after we have initialized the display so that we can use the display during an emergency reset
  checkEmergencyReset(); //Look to see if the RX pin is being pulled low

  setupTimer();  // Setup timer to control interval reading from buffer
  setupUART();   // initialize UART stuff (interrupts, enable, baud)
  setupSPI();    // Initialize SPI stuff (enable, mode, interrupts)
  setupTWI();    // Initialize I2C stuff (address, interrupt, enable)
  setupAnalog(); // Initialize the analog inputs
  setupMode();   // Determine which mode we should be in

  interrupts();  // Turn interrupts on, and les' go

  //Preload the display buffer with a default
  display.digits[0] = 1;
  display.digits[1] = 2;
  display.digits[2] = 3;
  display.digits[3] = 4;
}

// The display is constantly PWM'd in the loop()
void loop()
{
  if(deviceMode == MODE_DATA)
  {
    displayData();
  }
  else if(deviceMode == MODE_COUNTER)
  {
    displayCounter();
  }
  else if(deviceMode == MODE_ANALOG)
  {
    displayAnalog();
  }

  //We will loop if we've received a new device mode command
}

//This is the normal mode where we display whatever data is coming in over UART, SPI, and I2C
void displayData()
{
  while(deviceMode == MODE_DATA)
  {
    //Just hang out and update the display as new data comes in
    myDisplay.DisplayString(display.digits, display.decimals); //(numberToDisplay, decimal point location)

    serialEvent(); //Check the serial buffer for new data
  }
}

//Turn off the SPI and watch for increment pulses on the SDO pin, decrement on SDI
void displayCounter()
{
  SPCR = 0; //Disable all SPI interrupts that may be turned on

  int counterIncrement = SPI_MOSI; //Labeled SDI
  int counterDecrement = SPI_MISO; //Labeled SDO

  pinMode(counterIncrement, INPUT_PULLUP);
  pinMode(counterDecrement, INPUT_PULLUP);

  int counter = 0; //Watches the overall count
  boolean incrementCounted = false; //Watches the toggle the counter pins
  boolean decrementCounted = false;

  while(deviceMode == MODE_COUNTER) //Loop until we receive a different mode command
  {
    //Check to see if there has been a low/high pulse on increment
    if(digitalRead(counterIncrement) == LOW)
    {
      delay(1); //Check the pin 1 ms later - this is for debounce
      myDisplay.DisplayString(display.digits, 0); //Update display so that it doesn't blink

      if(digitalRead(counterIncrement) == LOW)
      {
        if(incrementCounted == false) //Only increment counter if this is a new pulse
        {
          counter++;
          incrementCounted = true; //We have now counted this pulse
        }
      }
    }
    else
    {
      //The increment pin is high, so sdo can be counted again
      incrementCounted = false;
    }

    //Check to see if there has been a low/high pulse on increment
    if(digitalRead(counterDecrement) == LOW)
    {
      delay(1); //Check the pin 1 ms later - this is for debounce
      myDisplay.DisplayString(display.digits, 0); //Update display so that it doesn't blink
      
      if(digitalRead(counterDecrement) == LOW)
      {
        if(decrementCounted == false) //Only increment counter if this is a new pulse 
        {
          counter--;
          decrementCounted = true; //We have now counted this pulse
        }
      }
    }
    else
    {
      //The increment pin is high, so sdo can be counted again
      decrementCounted = false;
    }

    //Display this count
    //char tempString[10]; //Used for sprintf
    sprintf(display.digits, "%4d", counter); //Convert counter into a string that is right adjusted

    
    //int tempCounter = counter;
    // for(int x = 0 ; x < 4 ; x++)
    // {
    // display.digits[3 - x] = (tempCounter % 10); //Pull off the right most digit and store in display array
    // tempCounter /= 10; //Shave number down by one digit
    // }

    myDisplay.DisplayString(display.digits, 0); //(numberToDisplay, no decimals during counter mode)

    serialEvent(); //Check the serial buffer for new data
  }  
}
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

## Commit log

2010-09-13 Lots of quick, minimal fixes. Lots more to come! -------------------------------------------- - Reorganized main.c and Serial-7-Seg.h. Only function prototypes, defines, and includes are in the .h fi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
    - Optimized a few of the global variable types and made volatile where necessary.
    - Got rid of a silly 1 argument switch statement.
2012-09-06 Version 3.0: Massive overhaul of the code. Added I2C Functionality. Added commands to better support I2C. Added buffering to serial inputs. The hardware has changed, pins have moved, current limiting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
    [Serial-7-Segment-Display.brd, Serial-7-Segment-Display.sch]
2012-09-06 Cleaning up directory structure. Adding a couple README's.
2012-10-07 Renamed INO file for easier use. Fixed typos and white space.
    Arduino has to have the file name same as directory. Removed version
    number from file. Repo should be able to handle file versions.
    [Serial_7_Segment_Display_Firmware.ino]
2012-10-21 Now uses SevSeg library for support of multiple types of displays.
    SevSeg library supports both common anode and cathode. Please test. From
    here, I plan to make many smaller firmware changes (that do not related
    to how segments are actually displayed).
    I need to get the products with a ATmega type backpack (Serial7Segment
    and OpenSegment) to this library so that we can use similar code, but
    with different pin definitions.
2012-10-21 Moved SPI pins to #defines.
2012-10-31 Added RX pin factory reset feature. Moved away from hardware UART setup.
    Many changes but the major one was adding the ability to reset the UART
    to 9600 when the RX is pulled low for a certain amount of time. This
    affected boot up, EEPROM locations, and the way that the UART is
    controlled. We now initialize the UART using standard Arduino calls
    instead of hardware registers. This commit works well with the
    BasicSerial example code. Even though there are quite a few code
    changes, the test code (BasicSerial) leads me to believe it works bug
    free.
    [S7S_Example_BasicSerial.ino, Serial_7_Segment_Display_Firmware.ino, settings.h]
2012-11-02 Now uses SetBrightness command.
    User supplies value from 0 to 100 percent instead of 0 to 255.
    SetBrightness does all the error correcting and map to get to
    delayMicrosecond value.
    [Serial_7_Segment_Display_Firmware.ino, settings.h]
2012-11-02 Adding additional baud rate levels.
    I didn't realize there was 76800 and 38400bps in there. They're back in
    there now.
    [S7S_Example_BasicSerial.ino, Serial_7_Segment_Display_Firmware.ino, settings.h]
2012-11-02 Added I2C interface example.
    Added a really simple I2C example sketch. Cleaned up some residual stuff
    in the main firmware. Moved the I2C receive event down below the main
    loop because it's not really an ISR.
2012-11-02 Added I2C brightness control sketch.
2012-11-03 Added SPI example sketches. Renamed files.
    Added basic SPI control and SPI control of settings. Works well. Also
    re-named some of the examples to make it more clear
2012-11-05 Addded different comments to show the mapping of PB6 and PB7.
    To use the additional pins, PB6 and PB7, on the ATmega328 we have to add
    some maps to the pins_arduino.h file. This allows Arduino to identify
    PB6 and digital pin 22, and PB7 as digital pin 23.
2012-11-05 Improved the software reset sketch. Uses strings now.
    [S7S_Example_Serial_SoftwareReset.ino, Serial_7_Segment_Display_Firmware.ino]
2012-11-05 Experimenting with volt meter display.
    Works well. Not sure where to put the A/D checking. Not in the main
    loop. Perhaps a dedicated function where we only go if a jumper is
    closed.
2012-11-26 Corrected a bad bug. Tested with new SevSeg library.
    I moved commandMode variable into the updateBufferData because I didn't
    think it was used anywhere else. The variable is not used anywhere else,
    but the function depends on the command being stored towards the end of
    the function. Summary: commandMode needs to be global. This fixes my
    mistake.
    [Serial_7_Segment_Display_Firmware.ino]
2013-01-01 Corrected device mode bug and library init bug.
    Device mode has to be an unsigned char because upon first power up the
    EEPROM is 0xFF (-1 or 255). The 1" displays are common cathode but with
    the PNP/NPN configuration of OpenSegment, it actually inverts the
    signals so we need to use common anode to get the library to work.
    [Serial_7_Segment_Display_Firmware.ino, System_Functions.ino]
2013-02-13 fixed some comments, re-worked pin labels in sch.
    Fixed comments in System_Functions.ino which mapped Arduino pins to
    display pins
    Some labels on the schematic did not match the display pin they
    connected to. Renamed those nets to make more sense.
    Added a pdf of current schematic, not sure if this'll be sustainable.
    Trying it out.
    Defaulted display type to S7S in the firmware.
    [Serial-7-Segment-Display.brd, Serial-7-Segment-Display.sch]
2015-02-14 Adding 7-bit I2C warning to example code. Added fast I2C example.
    OpenSegment works at 400kHz! Neat!
2015-05-14 hardware addon structure to matches 1.6 standards
    Added platform.txt
    Added necessary entries boards.txt
    Buried addon files in /hardware/sparkfun/avr/
2015-06-11 Added example on how to change I2C address
2015-12-18 created larger panel v31b
    [Serial-7-Segment-Display_Panel_v31b.brd]
2016-01-21 Adding check during reset to avoid skipping brightness value.
    [Serial_7_Segment_Display_Firmware.ino]
2017-02-13 Removed Arduino board support and change README to point users to the support in the Arduino_Boards repository.

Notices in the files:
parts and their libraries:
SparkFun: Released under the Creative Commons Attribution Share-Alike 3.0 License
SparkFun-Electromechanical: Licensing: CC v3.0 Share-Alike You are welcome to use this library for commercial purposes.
